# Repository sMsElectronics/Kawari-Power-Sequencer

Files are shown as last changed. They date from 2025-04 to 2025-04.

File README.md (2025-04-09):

# PC Boards available here: 
## [sMs Retro Electronics KoFi Shop](https://ko-fi.com/smsretroelectronics)
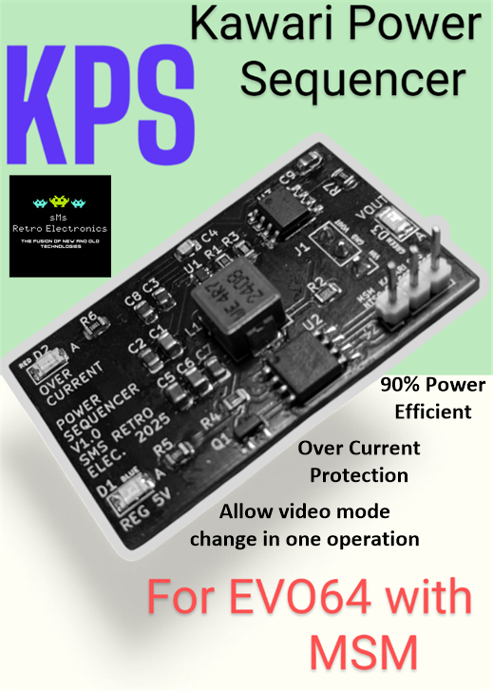
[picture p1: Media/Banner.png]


The Kawari Power Sequencer, known from here on as the “KPS”, is an electronically switched 5V regulator module that has been designed specifically for the EVO64 motherboard to work along side a Kawari VIC II and MSM. The KPS is a reliable, efficient, low noise, high frequency 5V switching regulator which remains very cool unlike linear regulators IC’s such as the common 7805. 

The KPS is installed onto the EVO64 motherboard’s 5V “CAN” regulator location that supplies power only to the VIC II 5V VCC socket pin.

The KPS allows the user to switch video standards on your EVO64 Commodore 64 between NTSC and PAL via the “Multi-Switch Module” MSM and a Kawari VIC II LARGE or SMALL board using a simple keyboard command. It will switch the video standard and recycle the Kawari’s power in one operation. No longer will the user have to manually switch the computers power OFF and ON after setting the video standard with an MSM. 

The KPS incorporates an over current sensing circuit that will sense when the output current goes above 780 mA and turns the 5V output off. A RED LED will indicate this condition. The KPS will remain latched in over current state until the input voltage is turned off and the over current condition is removed.  

sMs Retro Electronics A Division of sMs Electronics 2025
# LED Indicators: 

|LED|COLOR|DESCRIPTION
|:--:|:--|:--|
|D1|BLUE|REGULATOR 5V
|D2|RED|OVER CURRENT 
|D3|GREEN|KAWARI 5V 

 # KPS wiring details

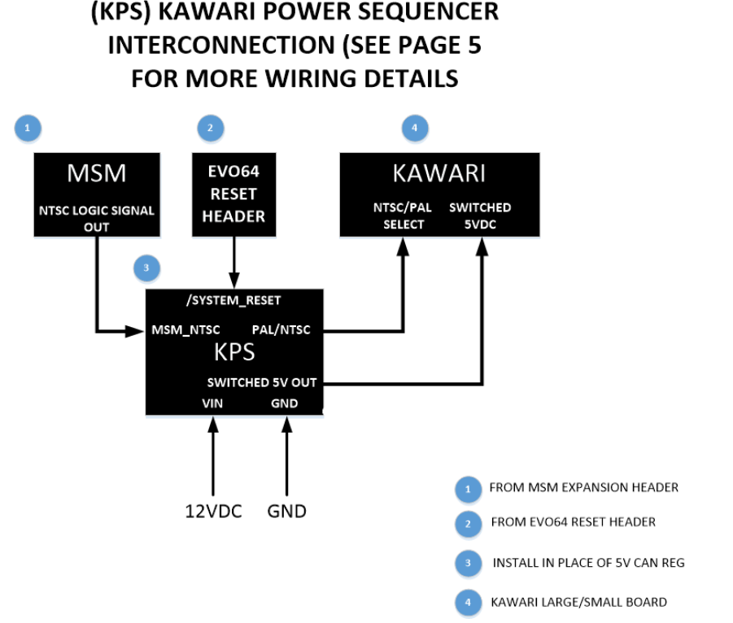
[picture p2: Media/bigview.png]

# Detailed Wiring:

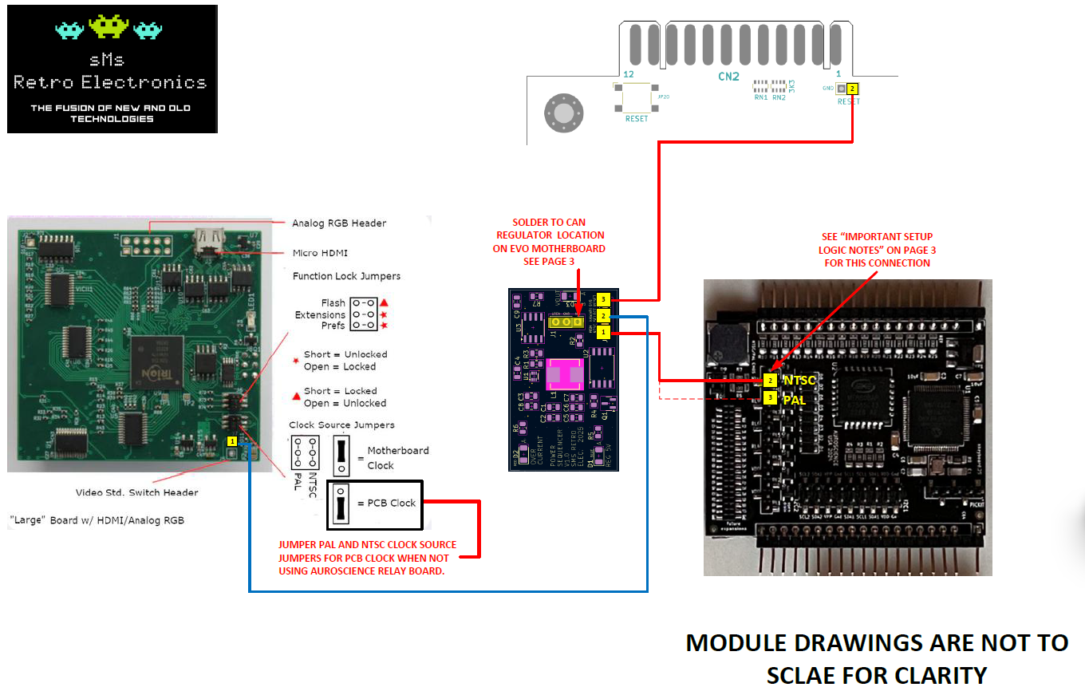
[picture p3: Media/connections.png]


 # KPS Firmware operation

The purpose of the KPS firmware is to allow the Kawari VICII hardware emulator to switch between NTSC and PAL video modes when commanded by an Retrospective EVO64 MSM controller without the need to recycle the computer power. It also provides an OVER CURRENT feature that will switch the power OFF to the Kawari if the current is >= 780 milliamperes. 

The firmware is essentially a state machine that monitors for any change, either a rising or falling edge, from the NTSC (or the PAL) logic output of the MSM and electronically cycles the power OFF then ON to the Kawari Vcc pin. This cycle is as follows: Turn power OFF when a change is detected, keep the power off until the boards RESET is asserted, at this point the power is returned to ON. The NTSC (or the PAL) logic output from the MSM is also routed to the Kawari video select pin header via an open drain MOSFET for 5V to 3.3V translation. 

Over current is latching. If an over current condition is detected, the firmware will turn the power OFF to the Kawari Vcc pin and remain OFF until the next system power cycle. all status is indicated with different color LED's 

 # KPS Build Notes & Cautions 

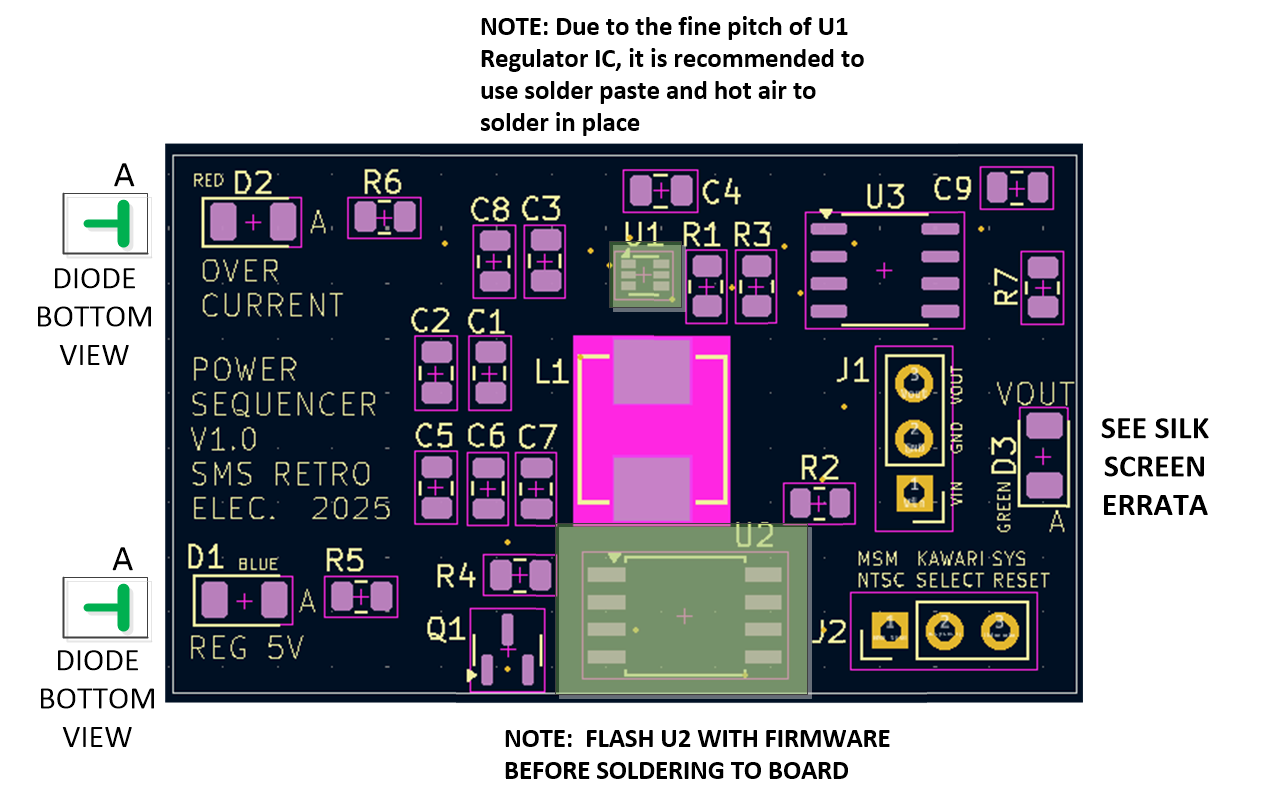
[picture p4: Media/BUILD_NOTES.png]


 If you are building your own KPS, make sure you flash U2 MCU with the firmware provided. All the instructions are provided in the "Flashing and HEX File" folder. When building your KPS, *it is recommended that you populate all components except your programmed U2 ATtiny85V-10S MCU and U3 AP2152A electronic power switch.* This is to prevent damage to these chips in cases where the regulator is not working properly due to errors in construction. These errors can lead to over voltage conditions that will easily damage your chips. It is recommended on first power up to check if the BLUE LED is ON and to measure the core regulator output voltage and check if its 5V +/- 5%. If it is not, then investigate why.    
  
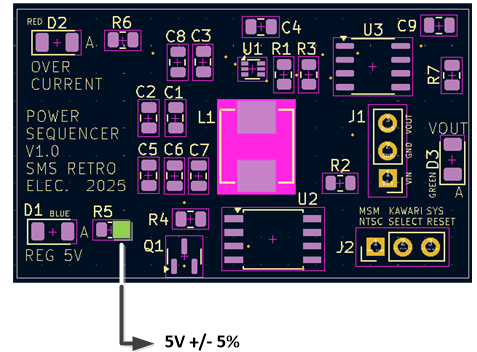
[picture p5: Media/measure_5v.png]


# PCB V1.0 Silkscreen Errata 

Silkscreen anode indication for D3 is incorrect. If D3 is installed as per the silkscreen, the diode will not illuminate. 

# Change FROM:
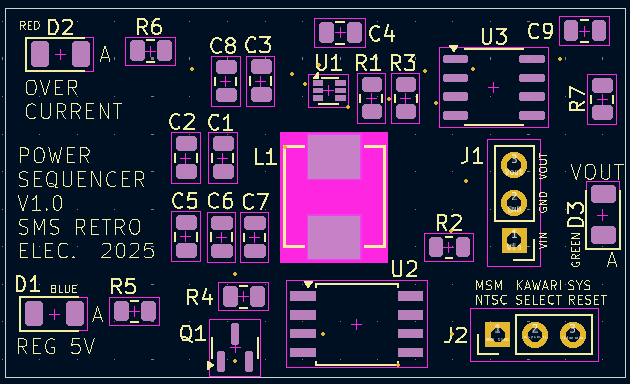
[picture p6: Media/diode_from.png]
  
# Change TO:
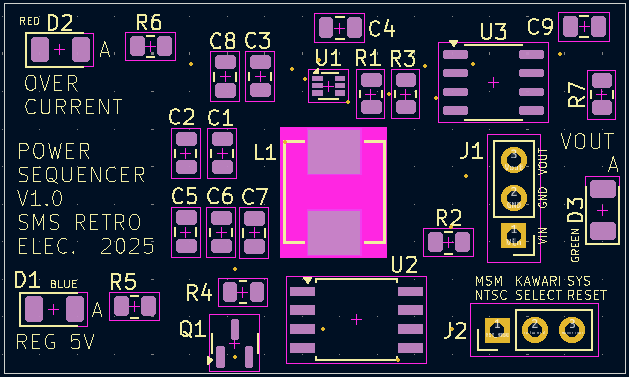
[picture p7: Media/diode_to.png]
  

Be sure to check out the full documentation ! PCB's will be available soon on my KoFi shop.

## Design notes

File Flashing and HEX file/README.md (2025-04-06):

# Flashing code into your ATtiny85

### If you are building a PC board from scratch, the following procedure outlines instructions on how to flash a new, blank, ATtiny85 device using the Xgegcu T48 Programmer. These programmers are widely available on Amazon for very reasonable prices. Below are links to the T48 programmer description and to download the Xgpro application software that will run on your PC. You will also need to download the "firmware_v1.x.hex" file from the "Flashing and HEX file" folder on this git repository and store it in a known location on your PC. This is the file you will LOAD later on in this procedure.  

### Here is a link to a YouTube video that shows the process on how to use the Xgegcu software 

## [Beginners Guide to the Xgecu T48 Programmer](https://youtu.be/36xP4uufo84?si=Jp_okfQR0br4AvkE)

## [Xgegcu T48 Description](http://forums.xgecu.com/viewthread.php?tid=694&extra=page%3D1)

## T48 and typical accessories that come with the bundle on Amazon that cost $79.00 USD as of this writing on 01/27/2025

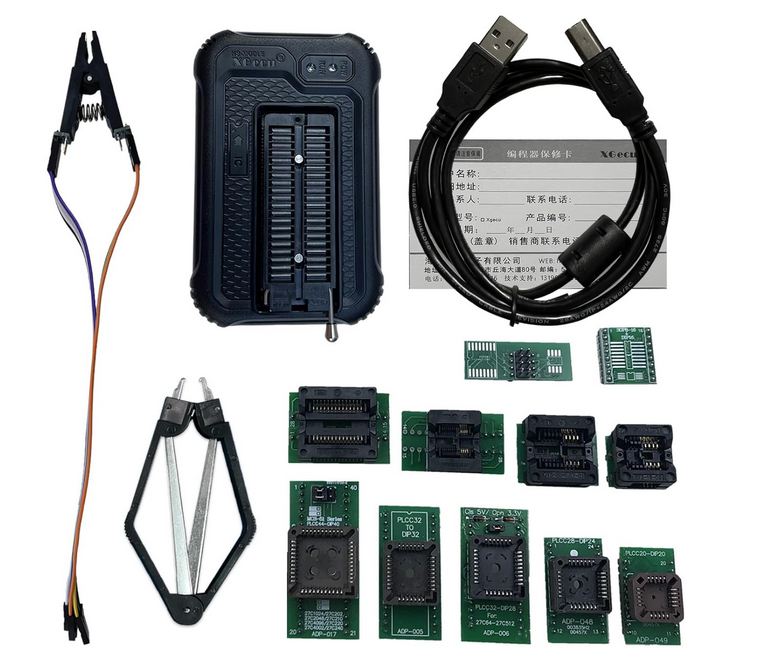
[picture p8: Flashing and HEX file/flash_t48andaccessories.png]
## 

## [Xgegcu Xgpro Application](http://www.xgecu.com/en/download.html?refreshed=1737924728727)

### Install the software per the instructions and run the application once completed. Attach the USB cable to the programmer and connect the other end to your PC's USB port. The PC should recognize the device. 

### After the application opens, the first step is to select your device as shown. Be sure to select the SOIC version. Either selection will work. The "V" only indicates a wider voltage range device. 
 
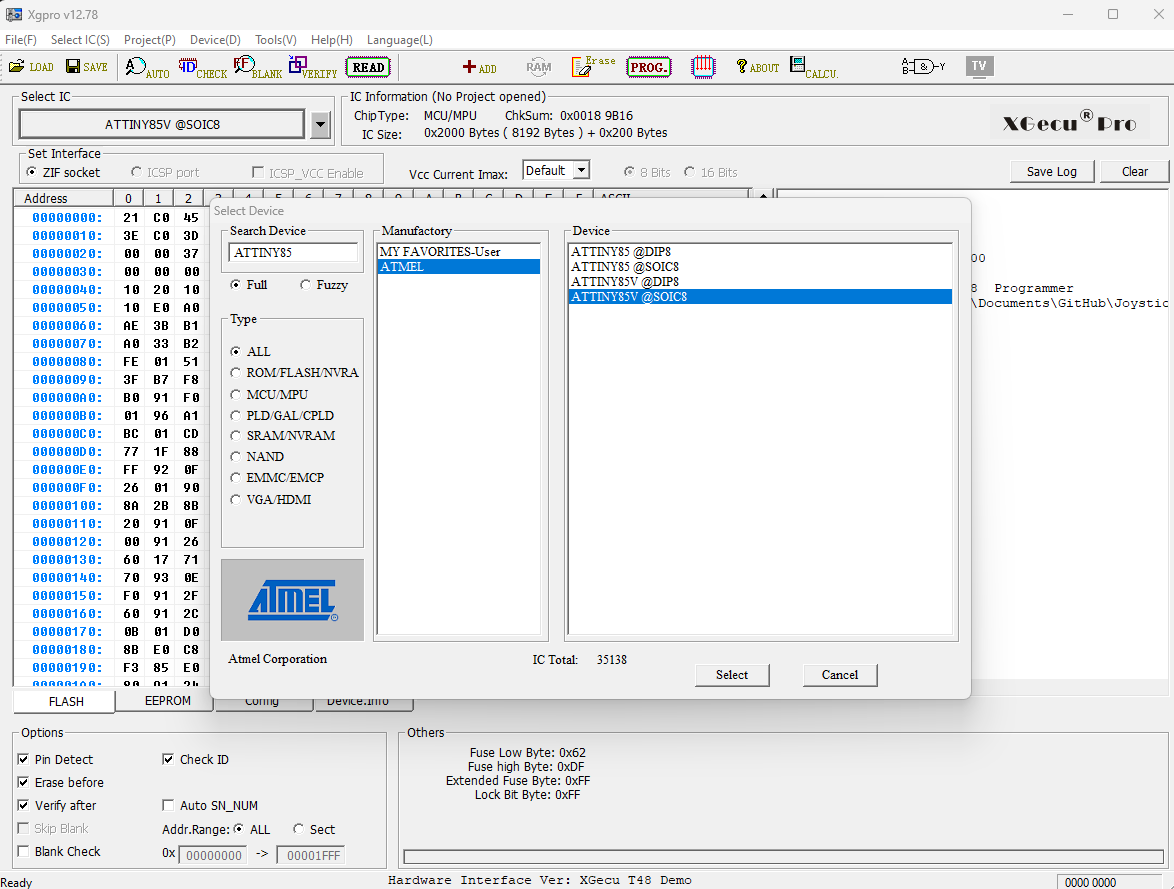
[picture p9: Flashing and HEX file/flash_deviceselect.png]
Select Device


### Locate the adapter (Yours may look different) and place it into the ZIF socket of the programmer. Be sure to orient pin 1 correctly as shown below. Now insert the MCU chip into the adapter as shown being sure that pin 1 is in the correct orientation.   

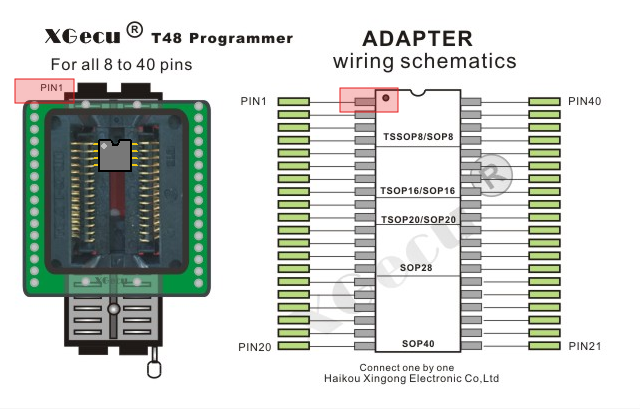
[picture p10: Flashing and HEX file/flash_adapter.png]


### LOAD the HEX file into memory as shown below. Select OK. The memory view should like shown below. 

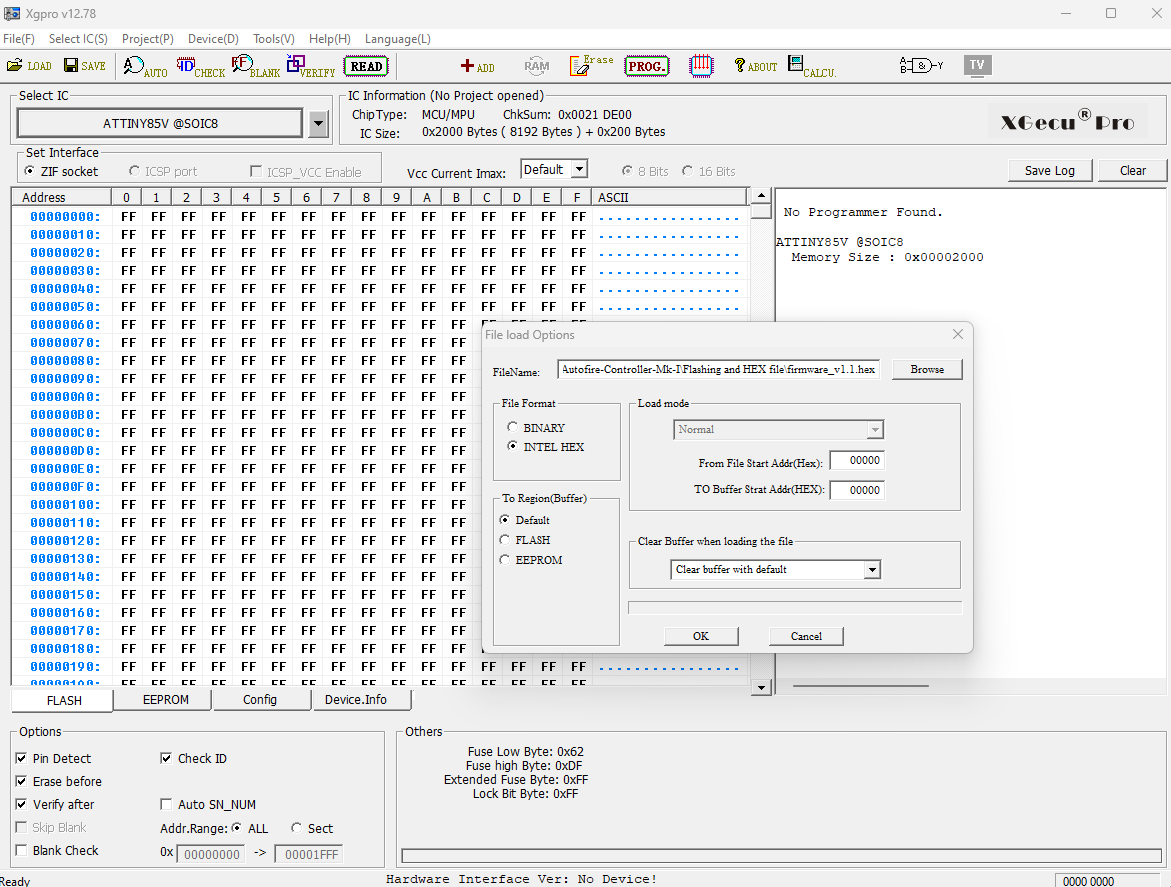
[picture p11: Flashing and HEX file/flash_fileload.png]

### View of memory after LOAD
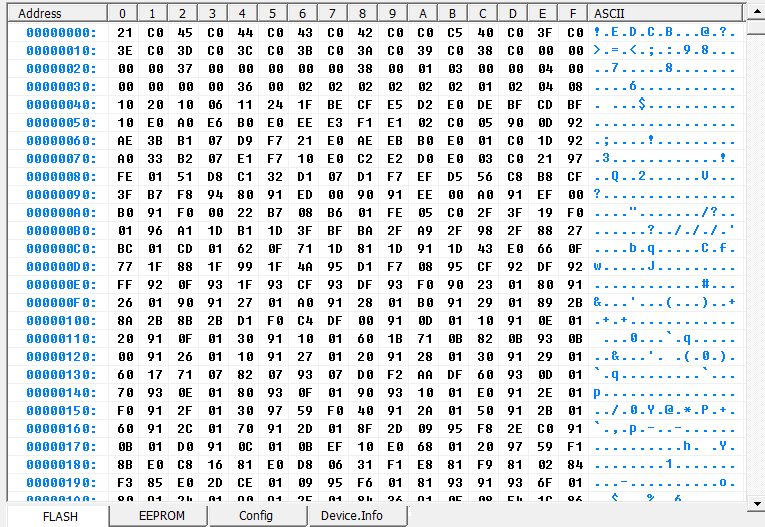
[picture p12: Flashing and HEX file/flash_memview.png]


### Select the fuse options as shown below. This will disable the RESET pin and turn the clock divider OFF thus the MCU will be running the internal oscillator at approximately 4 MHz without the need for an external crystal.    

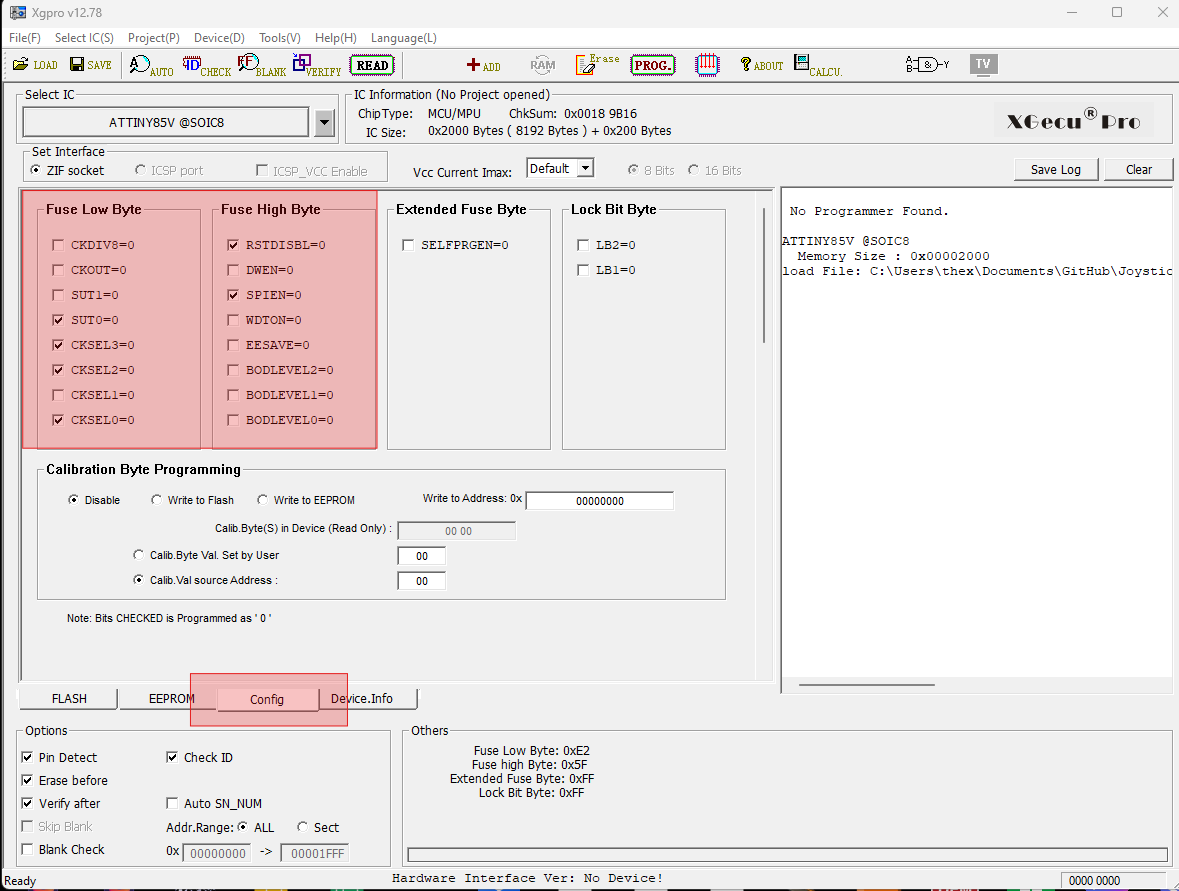
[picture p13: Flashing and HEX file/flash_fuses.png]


### Select PROGRAM and the windows will appear below. Make the selections in the program range. It is only important to select the FLASH and CONFIG memories. The flash memory and fuse bits will only be programmed. 

Now select PROGRAM and the progress will be shown in the window. When completed, SUCCESS should be visible. You can now remove the chip and solder to you PCB.  

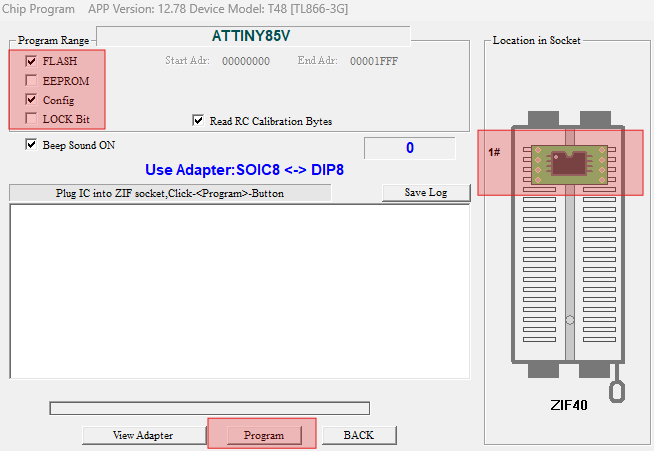
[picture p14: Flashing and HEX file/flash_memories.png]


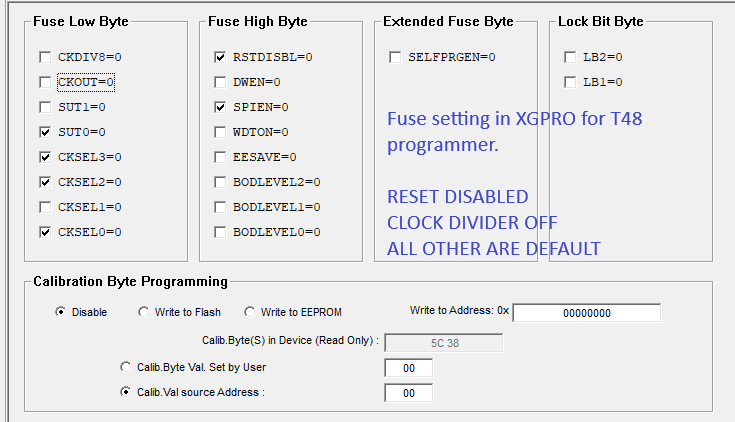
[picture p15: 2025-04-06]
Flashing and HEX file/fuse_settings_t48.PNG

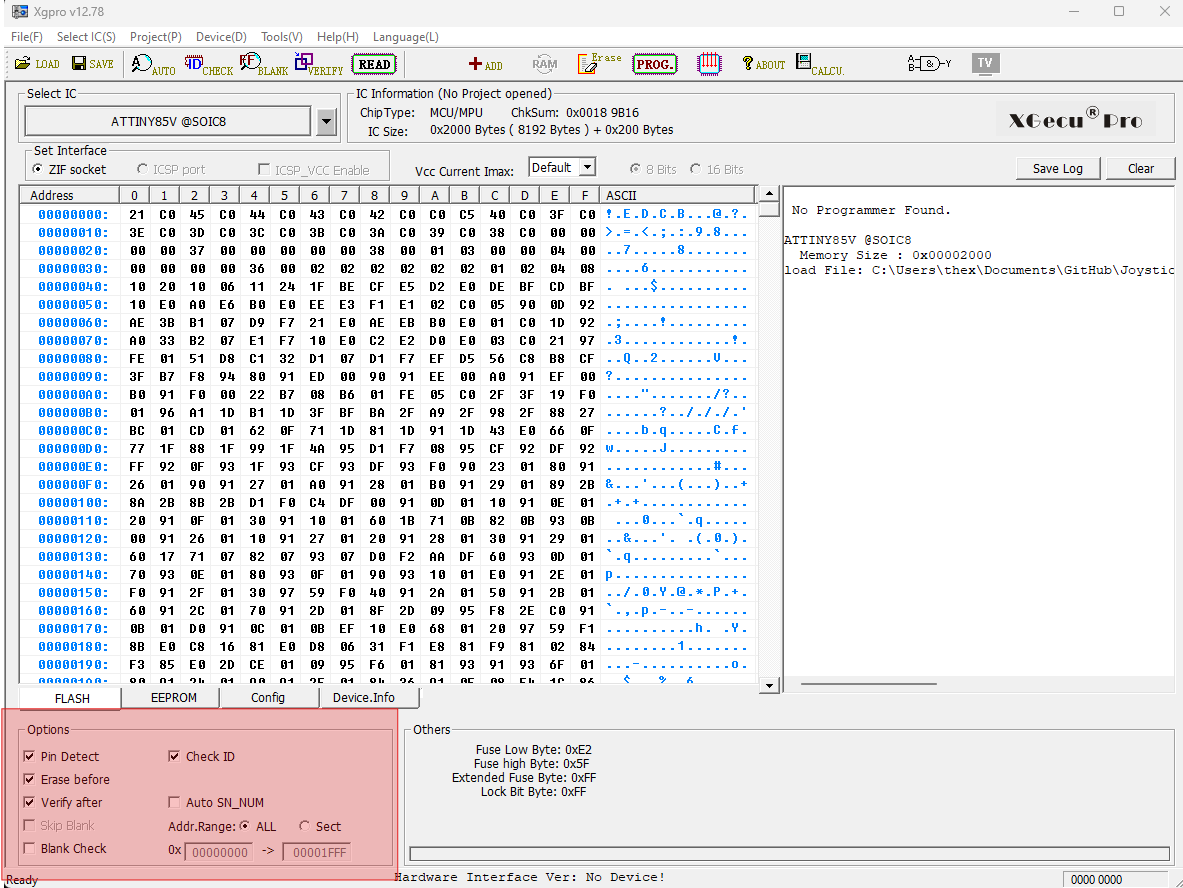
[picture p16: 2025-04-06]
Flashing and HEX file/flash_options.png

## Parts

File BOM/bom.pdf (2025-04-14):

bom

Designation | Footprint
C1 | 0805
C2, C3, C7, C8, 0805
C4 | 0805
C5, C6 | 0805
D1 | 1206
D2 | 1206
D3 | 1206
J1, J2 | PinHeader_1x03_P2.54mm_Vertical
L1 | SMD/SMT
Q1 | SOT-23
R1, R4 | 0805
R2 | 0805
R3 | 0805
R5, R6, R7 | 0805
U1 | SOT-563
U2 | SOIC-8W_5.3x5.3mm_P1.27mm
U3 | SO-8_3.9x4.9mm_P1.27mm

bom

Part Number | Quantity | Value
GRM21BR61E106MA73L | 1 | 10 uF
GCJ21BR71H104MA01L | 5 | .1 uF
C0805C180J3GACTU | 1 | 18 pF
GRM21BR61A226ME44L | 2 | 22 uF
SM1206NBWC-IL | 1 | BLUE LED SMD 1206
SM1206RC-IL | 1 | RED LED SMD 1206
SM1206GC | 1 | GREEN LED SMD 1206
HTSW-110-07-F-S | 2 | Conn_01x03_Pin
74437349047 | 1 | 4.7 uH
| 1 | MOSFET P-CHANNEL
RT0805FRE07100KL | 2 | 100K 1% 1/8W
RT0805FRE07220KL | 1 | 220K 1% 1/8W
RT0805FRE0730KL | 1 | 30K 1% 1/8W
RT0805FRE071KL | 3 | 1K 1% 1/8W
TPS563206DRLR | 1 | Switching Voltage Regulator
ATtiny85V-10S | 1 | ATtiny85V-10S
| 1 | Dual Power Switch

DMP68D1LQ-7

AP2152ASG-13

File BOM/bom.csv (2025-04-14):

Designation | Footprint | Part Number | Quantity | Value
C1 | 0805 | GRM21BR61E106MA73L | 1 | 10 uF
C2, C3, C7, C8, C9 | 0805 | GCJ21BR71H104MA01L | 5 | .1 uF
C4 | 0805 | C0805C180J3GACTU | 1 | 18 pF
C5, C6 | 0805 | GRM21BR61A226ME44L | 2 | 22 uF
D1 | 1206 | SM1206NBWC-IL | 1 | BLUE LED SMD 1206
D2 | 1206 | SM1206RC-IL | 1 | RED LED SMD 1206
D3 | 1206 | SM1206GC | 1 | GREEN LED SMD 1206
J1, J2 | PinHeader_1x03_P2.54mm_Vertical | HTSW-110-07-F-S | 2 | Conn_01x03_Pin
L1 | SMD/SMT | 74437349047 | 1 | 4.7 uH
Q1 | SOT-23 | DMP68D1LQ-7 | 1 | MOSFET P-CHANNEL
R1, R4 | 0805 | RT0805FRE07100KL | 2 | 100K 1% 1/8W
R2 | 0805 | RT0805FRE07220KL | 1 | 220K 1% 1/8W
R3 | 0805 | RT0805FRE0730KL | 1 | 30K 1% 1/8W
R5, R6, R7 | 0805 | RT0805FRE071KL | 3 | 1K 1% 1/8W
U1 | SOT-563 | TPS563206DRLR | 1 | Switching Voltage Regulator
U2 | SOIC-8W_5.3x5.3mm_P1.27mm | ATtiny85V-10S | 1 | ATtiny85V-10S
U3 | SO-8_3.9x4.9mm_P1.27mm | AP2152ASG-13 | 1 | Dual Power Switch

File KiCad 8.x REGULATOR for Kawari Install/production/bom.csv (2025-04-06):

Designator | Footprint | Quantity | Value | LCSC Part #
C1 | 0805 | 1 | 10 uF
C2, C3, C7, C8, C9 | 0805 | 5 | .1 uF
C4 | 0805 | 1 | 18 pF
C5, C6 | 0805 | 2 | 22 uF
D1 | 1206 | 1 | BLUE LED SMD 1206
D2 | 1206 | 1 | RED LED SMD 1206
D3 | 1206 | 1 | GREEN LED SMD 1206
J1, J2 | PinHeader_1x03_P2.54mm_Vertical | 2 | Conn_01x03_Pin
L1 | WE-LHMI_7050 | 1 | 4.7 uH
Q1 | SOT-23 | 1 | 2N7002
R1, R4 | 0805 | 2 | 100K
R2 | 0805 | 1 | 220K
R3 | 0805 | 1 | 30K
R5, R6, R7 | 0805 | 3 | 1K
U1 | SOT-563 | 1 | TPS563206DRLR
U2 | SOIC-8W_5.3x5.3mm_P1.27mm | 1 | ATtiny85V-10S
U3 | SO-8_3.9x4.9mm_P1.27mm | 1 | AP2152A

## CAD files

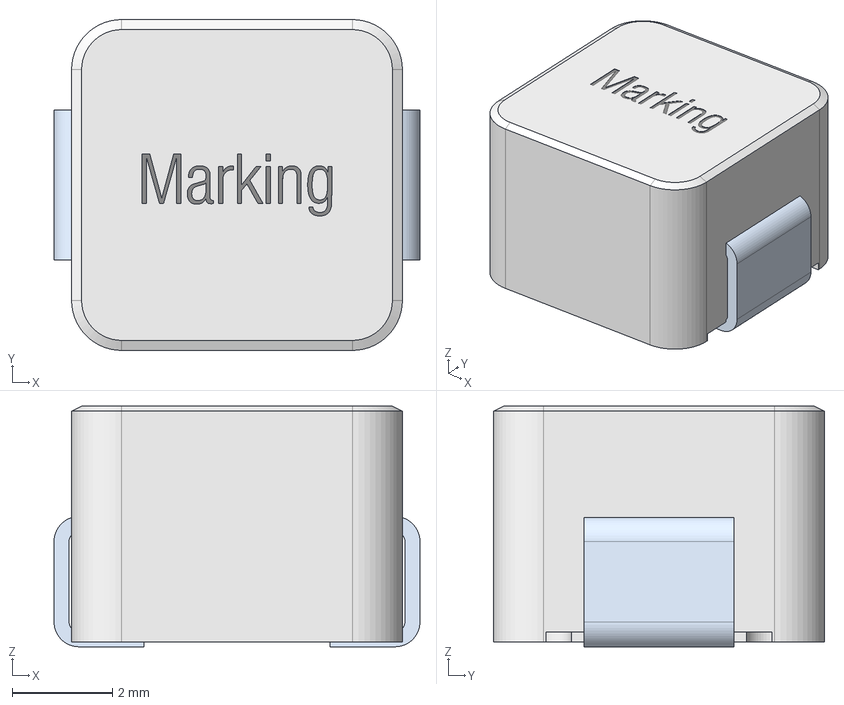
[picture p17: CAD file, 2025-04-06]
KiCad 8.x REGULATOR for Kawari Install/NEW Design/74437349047/WE-LHMI_7050.step
7.30 x 6.60 x 4.80 mm

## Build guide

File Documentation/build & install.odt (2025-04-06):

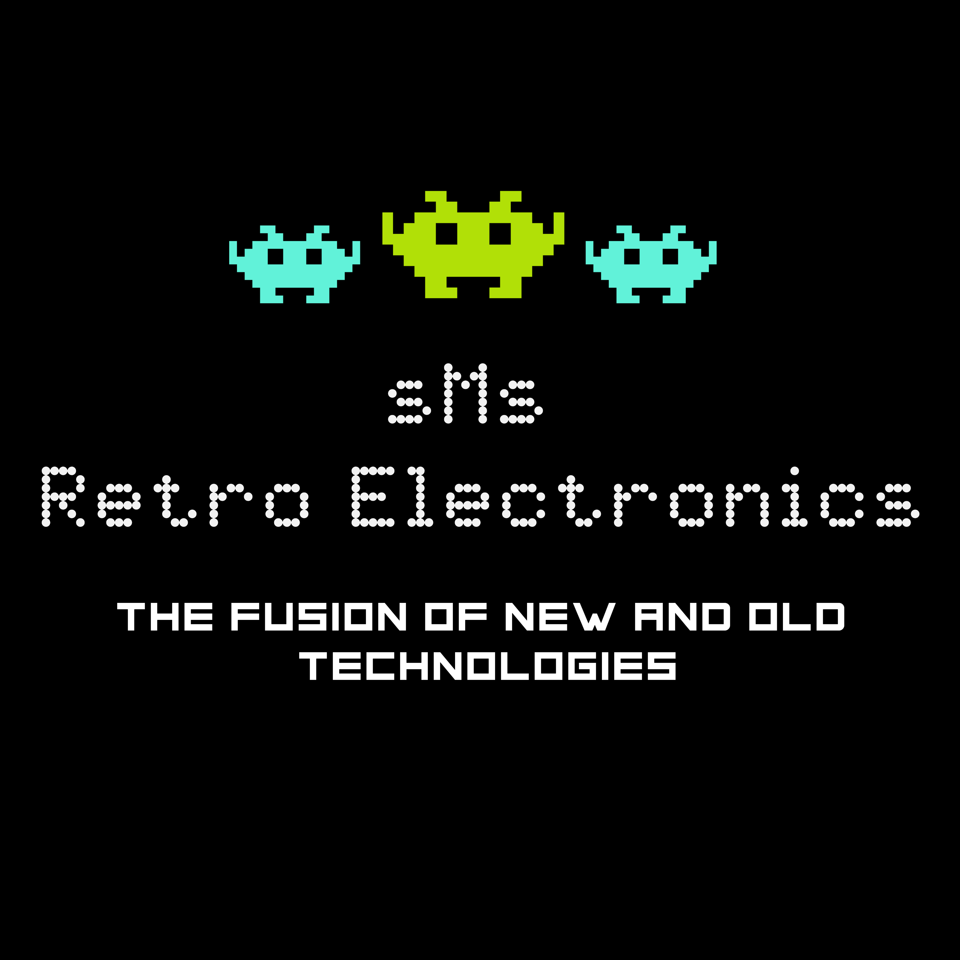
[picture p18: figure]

EVO64 KPS (Kawari Power Sequencer)

PC Board Version V1.0 : MCU Firmware Version V1.0

The document covers:

INSTALLATION & OPERATION

for Support: Bill Manganaro thex@optonline.net

or give a shout on the Discord channel: C64EVO, Expansions / Add-Ons

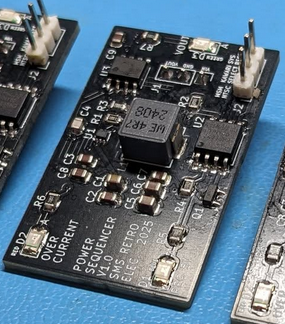
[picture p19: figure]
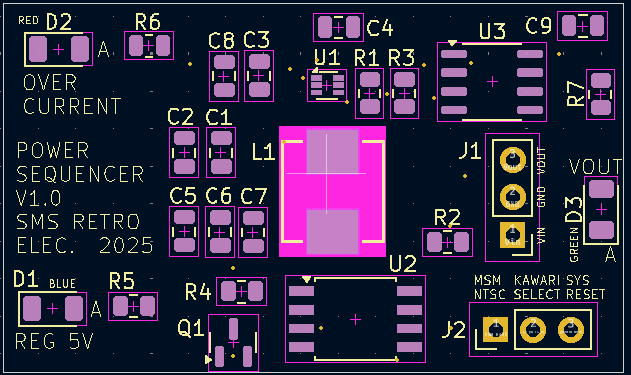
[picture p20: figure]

Whats is the Kawari Power Sequencer?

The Kawari Power Sequencer, known from here on as the “KPS”, is an electronically switched 5V regulator module that has been designed specifically for the EVO64 motherboard to work along side a Kawari VIC II and MSM. The KPS is a reliable, efficient, low noise, high frequency 5V switching regulator which remains very cool unlike linear regulators IC’s such as the common 7805.

The KPS is installed onto the EVO64 motherboard’s 5V “CAN” regulator location that supplies power only to the VIC II 5V VCC socket pin.

The KPS allows the user to switch video standards on your EVO64 Commodore 64 between NTSC and PAL via the “Multi-Switch Module” MSM and a Kawari VIC II LARGE or SMALL board using a simple keyboard command. It will switch the video standard and recycle the Kawari’s power in one operation. No longer will the user have to manually switch the computers power OFF and ON after setting the video standard with an MSM.

Over Current Safety Feature

The KPS incorporates an over current sensing circuit that will sense when the output current goes above 780 mA and turns the 5V output off. A RED LED will indicate this condition. The KPS will remain latched in over current state until the input voltage is turned off and the over current condition is removed.

This document illustrates all the details necessary to install the KPS, wire the necessary connections, and operate your KPS. The board you receive has been fully tested before shipping to insure that it works as designed.

Connector and Indicator Reference

1) Vout INDICATOR. - Green LED that indicates 5V power is present to the Kawari VIC II.

2) OVER CURRENT INDICATOR. - Red LED that indicates an over current condition is present.

3) REGULATOR INDICATOR. - Blue LED that indicates the internal 5V is working.

4) KPS INPUT AND OUTPUT CONNECTOR (J2)

PIN 1 [SQUARE PAD] LOGIC SIGNAL FROM MSM (INPUT)

PIN 2 KAWARI SELECT SIGNAL TO KAWARI (OUTPUT)

PIN 3 SYSTEM RESET SIGNAL (INPUT)

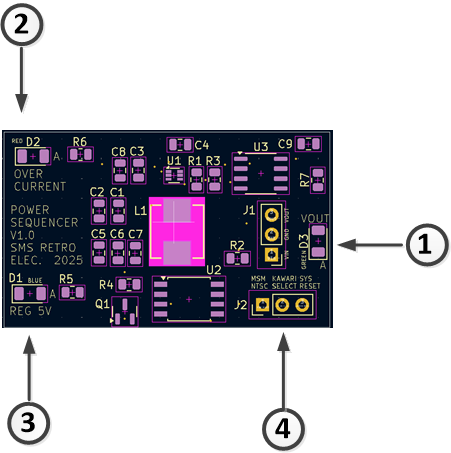
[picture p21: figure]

Overall View of Installation

The following diagram shows all the components necessary for the system to work.

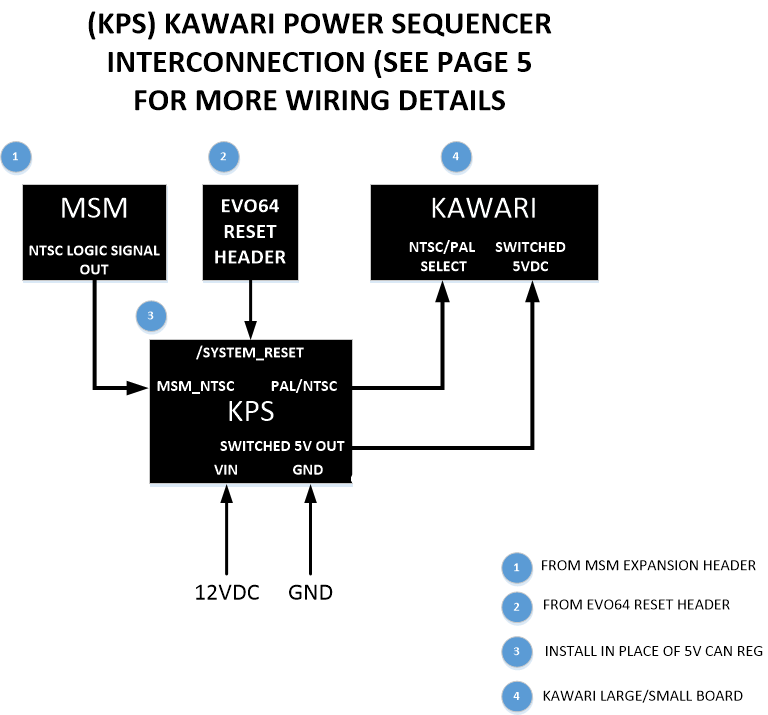
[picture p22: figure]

Detailed Installation

If a 5V regulator is already installed on your EVO motherboard, desolder it and clear the pad holes of any remaining solder. Install the KPS as shown below noting the position of the J1 pin header. Also, please read the “IMPORTANT SETUP LOGIC NOTES” so that you use the correct logic output (NTSC or PAL) from the MSM based on your VIC II emulation mode saved in the Kawari setup utility.

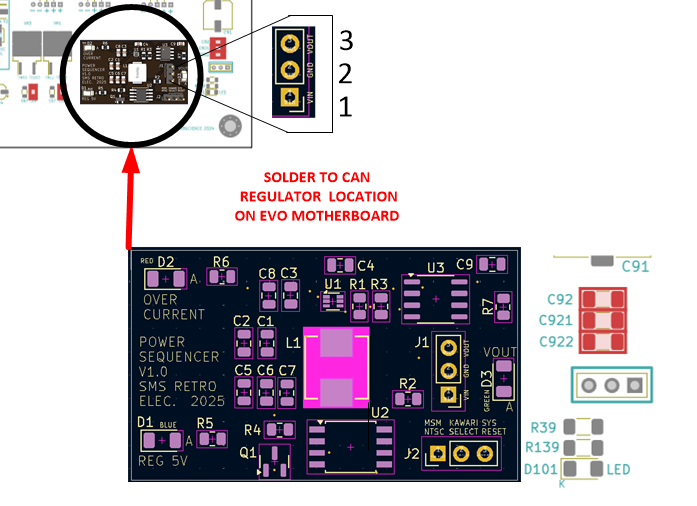
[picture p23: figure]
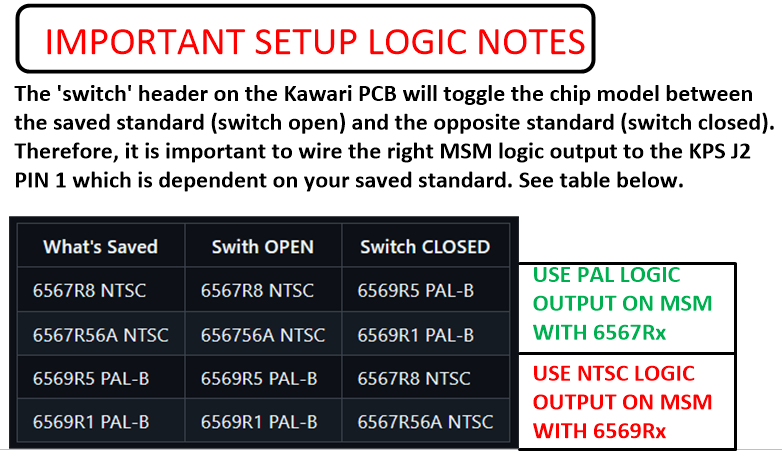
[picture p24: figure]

On your Kawari, if you do not have a VICII oscillator control module, set your clock select jumpers to “PCB Clock” as shown in the diagram below and connect the wiring as shown. Its important to check all the connections after you’re done.

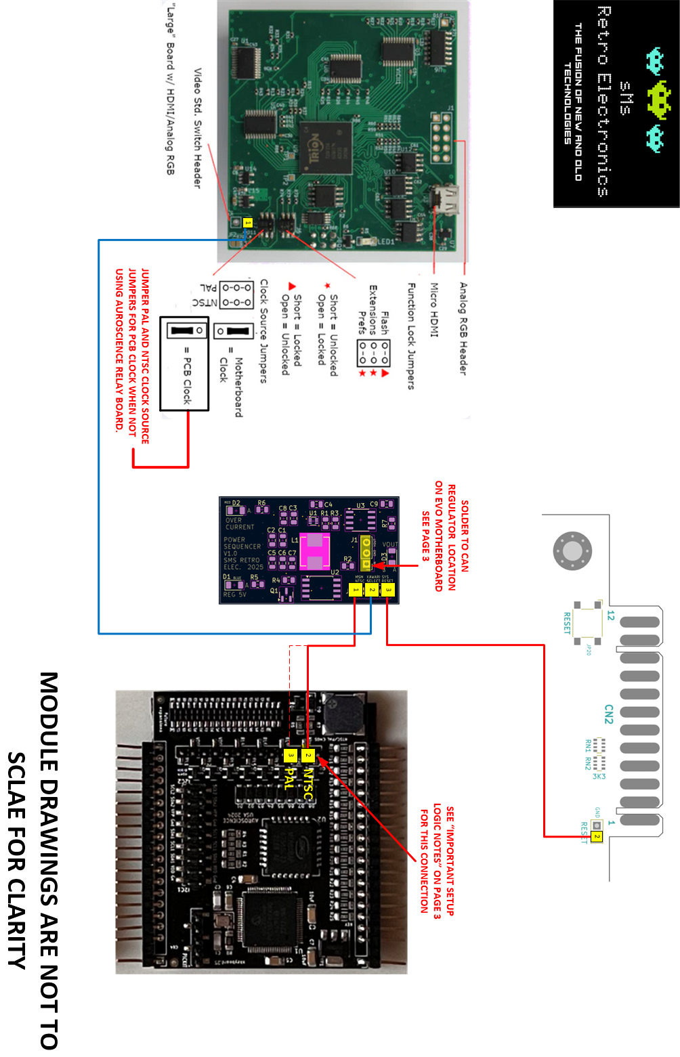
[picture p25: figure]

First Turn On

Setup your computer with an HDMI monitor connected (If using kawari Large) and turn the computer power on. On the KPS, the green LED (1) and blue LED (3) should be on and the red LED (2) should be off. Your kawari red LED should also be on. You should see a display like you normally do on your monitor. If you see this then you are in good shape. If the KPS red LED is on, and the green LED is off, this indicates an over current issue of >780 mA and must be investigated. The MSM LCD should look normal as shown with your current settings. We are interested in the VID: PAL or NTSC portion of the LCD. Your monitor should always reflect the setting shown on the MSM LCD.

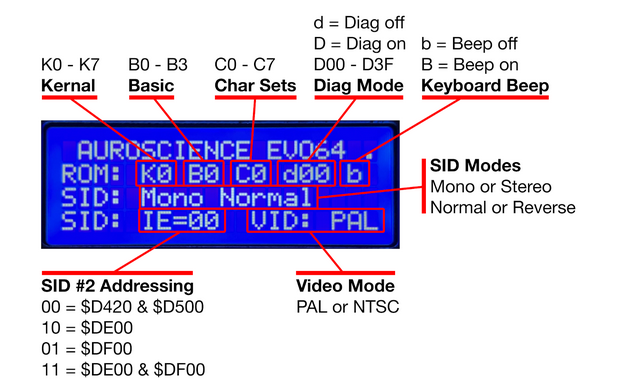
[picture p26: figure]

To change the VIC II video mode, see the instructions below. When changing the video mode, the KPS green and Kawari red LED’s will flash for about a second and then remain on. This indicates the Kawari power has been successfully cycled off then on in order for it to configure itself properly. The video output standard should now be what’s indicated on your MSM’s LCD. Here is a quick sanity check to make sure you are in the correct video standard. Type this BASIC command at the computer prompt and if it returns a “0”, you’re in NTSC. If it returns a “1”, you’re in PAL

PRINT PEEK (678)

Instructions to Change Video Mode on MSM:

VICII VIDEO MODE: video

This command enables you to toggle between PAL and NTSC, as long as you have all the necessary add-ons. To toggle between video modes, you simply enter the COMMAND MODE sequence (Reference below), followed by video and RETURN.

- After changing a video mode, Kawari will be automatically power cycled by the KPS module you’ve just installed.

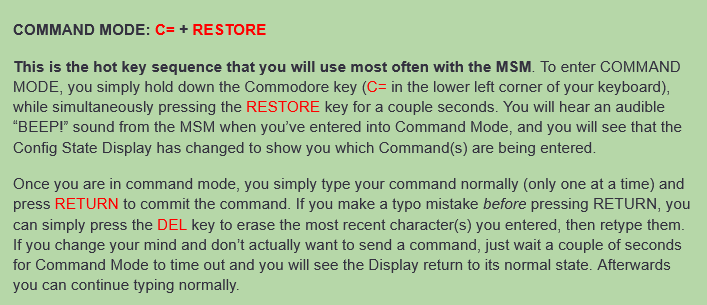
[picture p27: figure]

(https://docs.google.com/document/d/1dWGB7BDyYcx3Wr9RBiRH9s14tvGeOEsOeAum02HLLDU/edit?tab=t.0)The web link to the full MSM documentation is located here:

WEB LINK TO : MSM DOCUMENTATION (https://docs.google.com/document/d/1dWGB7BDyYcx3Wr9RBiRH9s14tvGeOEsOeAum02HLLDU/edit?tab=t.0)

If everything has worked than your installation has been a success. If things do not seem to be working correctly, then proceed to the following troubleshooting table.

TROUBLESHOOTING

SYMPTOM | ACTION
No LED’s on KPS are on | Check for 12V at the Vin of the KPS
Just the Blue LED is on | Check that the KPS is connected to the mainboard’s RESET header and that the connection is on the correct pin of the header
The red LED is on | The is a short at the KPS output. Remove the Kawari and see if the short goes away.
The power cycling does not occur | Check that the KPS is connected to the MSM “NTSC” logic output. Make sure the connection is on the correct pin.

Page 9 sMs Retro Electronics KPS Rev 1.0 Rev “A”

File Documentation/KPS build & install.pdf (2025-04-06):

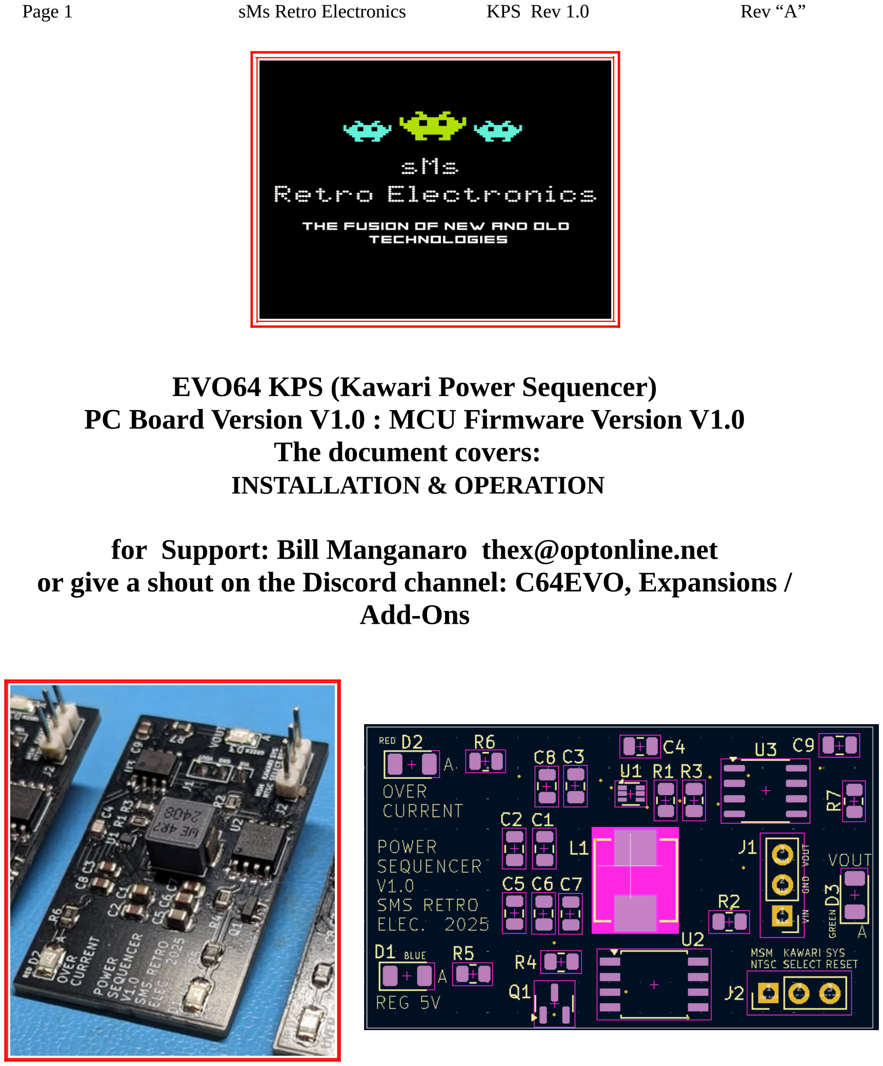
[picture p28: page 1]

Page 1 | sMs Retro Electronics | KPS Rev 1.0 | Rev “A”

EVO64 KPS (Kawari Power Sequencer) PC Board Version V1.0 : MCU Firmware Version V1.0 The document covers:
INSTALLATION & OPERATION

for Support: Bill Manganaro thex@optonline.net or give a shout on the Discord channel: C64EVO, Expansions / Add-Ons

Page 2 | sMs Retro Electronics | KPS Rev 1.0 | Rev “A”
Whats is the Kawari Power Sequencer?

The Kawari Power Sequencer, known from here on as the “KPS”, is an electronically switched 5V regulator module that has been designed specifically for the EVO64 motherboard to work along side a Kawari VIC II and MSM. The KPS is a reliable, efficient, low noise, high frequency 5V switching regulator which remains very cool unlike linear regulators IC’s such as the common 7805.

The KPS is installed onto the EVO64 motherboard’s 5V “CAN” regulator location that supplies power only to the VIC II 5V VCC socket pin.

The KPS allows the user to switch video standards on your EVO64 Commodore 64 between NTSC and PAL via the “Multi-Switch Module” MSM and a Kawari VIC II LARGE or SMALL board using a simple keyboard command. It will switch the video standard and recycle the Kawari’s power in one operation. No longer will the user have to manually switch the computers power OFF and ON after setting the video standard with an MSM.

Over Current Safety Feature

The KPS incorporates an over current sensing circuit that will sense when the output current goes above 780 mA and turns the 5V output off. A RED LED will indicate this condition. The KPS will remain latched in over current state until the input voltage is turned off and the over current condition is removed.

This document illustrates all the details necessary to install the KPS, wire the necessary connections, and operate your KPS. The board you receive has been fully tested before shipping to insure that it works as designed.

Page 3 | sMs Retro Electronics | KPS Rev 1.0 | Rev “A”
Connector and Indicator Reference
1) Vout INDICATOR. - Green LED that indicates 5V power is present to the Kawari VIC II.
2) OVER CURRENT INDICATOR. - Red LED that indicates an over current condition is present.
3) REGULATOR INDICATOR. - Blue LED that indicates the internal 5V is working.
4) KPS INPUT AND OUTPUT CONNECTOR (J2)
PIN 1 [SQUARE PAD] LOGIC SIGNAL FROM MSM | (INPUT)
PIN 2 KAWARI SELECT SIGNAL TO KAWARI | (OUTPUT)
PIN 3 SYSTEM RESET SIGNAL | (INPUT)

Page 4 | sMs Retro Electronics | KPS Rev 1.0 | Rev “A”
Overall View of Installation

The following diagram shows all the components necessary for the system to work.

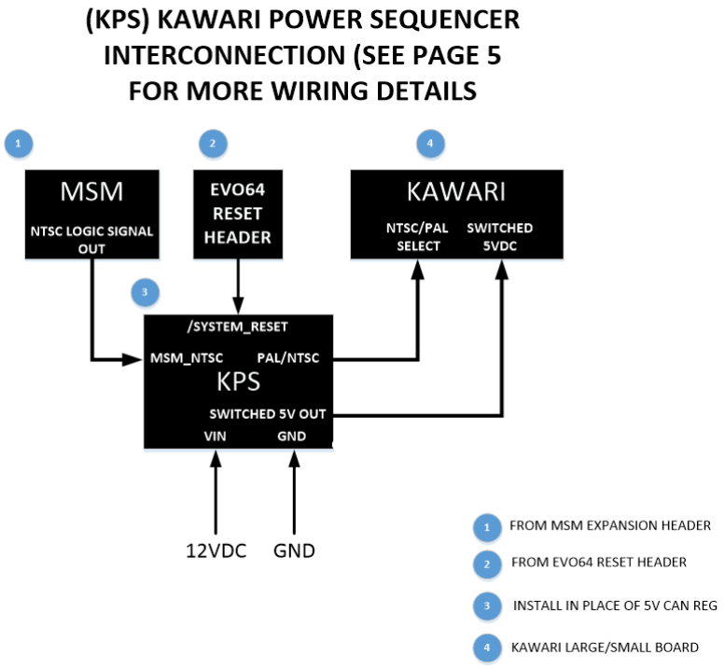
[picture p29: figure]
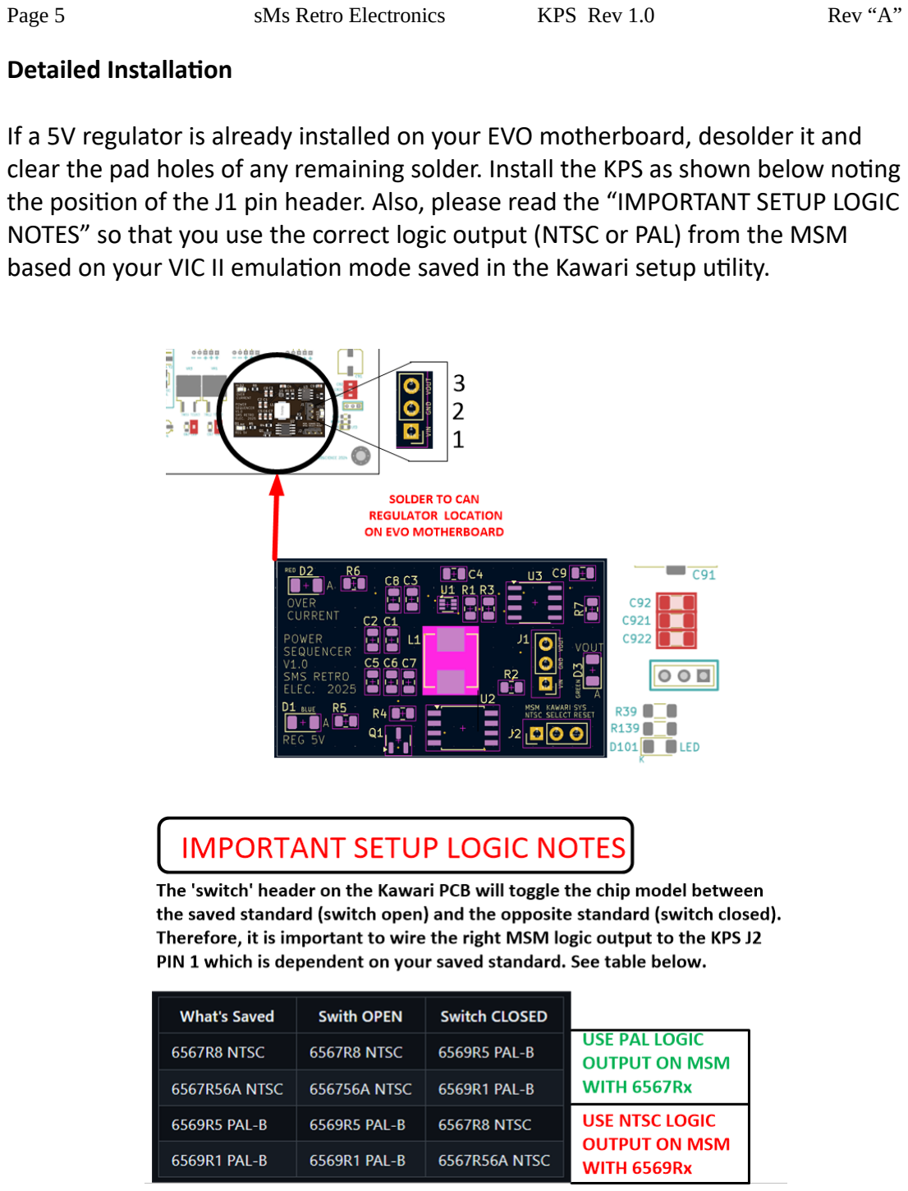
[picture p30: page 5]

Page 5 | sMs Retro Electronics | KPS Rev 1.0 | Rev “A”
Detailed Installation

If a 5V regulator is already installed on your EVO motherboard, desolder it and clear the pad holes of any remaining solder. Install the KPS as shown below noting the position of the J1 pin header. Also, please read the “IMPORTANT SETUP LOGIC NOTES” so that you use the correct logic output (NTSC or PAL) from the MSM based on your VIC II emulation mode saved in the Kawari setup utility.

Page 6 | sMs Retro Electronics | KPS Rev 1.0 | Rev “A”
On your Kawari, if you do not have a VICII oscillator control module, set your clock select jumpers to “PCB Clock” as shown in the diagram below and connect the wiring as shown. Its important to check all the connections after you’re done.

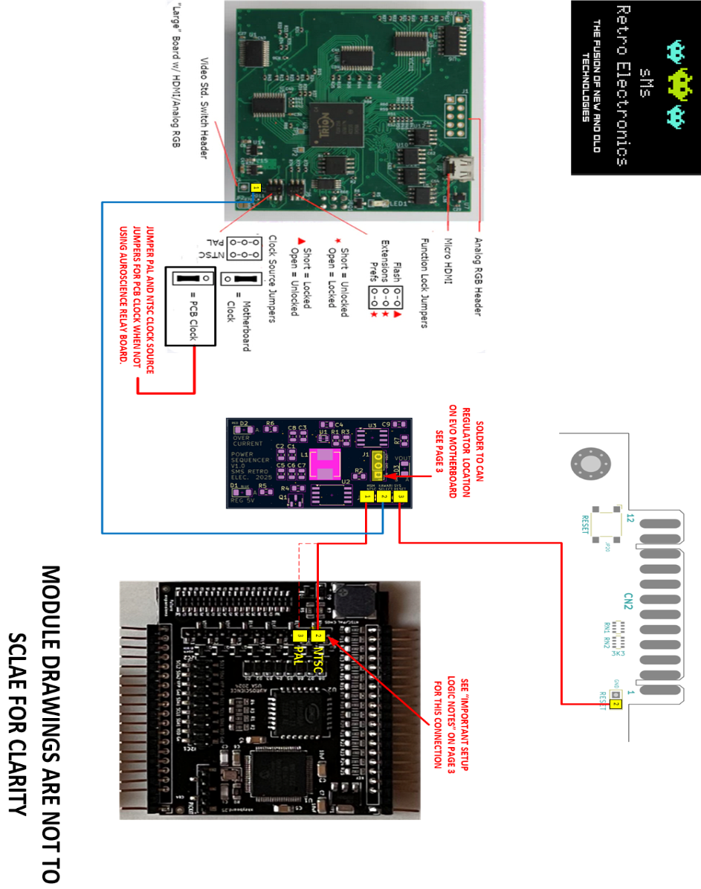
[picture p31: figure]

Page 7 | sMs Retro Electronics | KPS Rev 1.0 | Rev “A”

First Turn On


Setup your computer with an HDMI monitor connected (If using kawari Large) and turn the computer power on. On the KPS, the green LED (1) and blue LED (3) should be on and the red LED (2) should be off. Your kawari red LED should also be on. You should see a display like you normally do on your monitor. If you see this then you are in good shape. If the KPS red LED is on, and the green LED is off, this indicates an over current issue of >780 mA and must be investigated. The MSM LCD should look normal as shown with your current settings. We are interested in the VID: PAL or NTSC portion of the LCD. Your monitor should always reflect the setting shown on the MSM LCD.

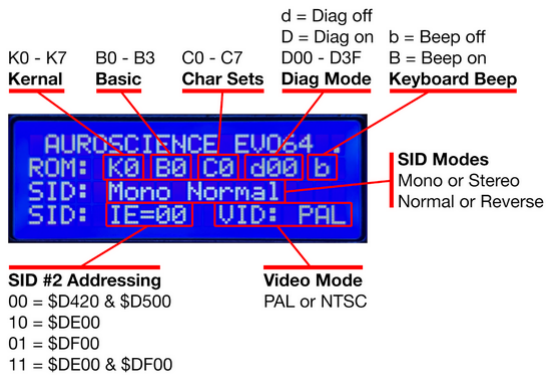
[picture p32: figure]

Page 8 | sMs Retro Electronics | KPS Rev 1.0 | Rev “A”
To change the VIC II video mode, see the instructions below. When changing the video mode, the KPS green and Kawari red LED’s will flash for about a second and then remain on. This indicates the Kawari power has been successfully cycled off then on in order for it to configure itself properly. The video output standard should now be what’s indicated on your MSM’s LCD. Here is a quick sanity check to make sure you are in the correct video standard. Type this BASIC command at the computer prompt and if it returns a “0”, you’re in NTSC. If it returns a “1”, you’re in PAL
PRINT PEEK (678)
Instructions to Change Video Mode on MSM:
VICII VIDEO MODE: video

This command enables you to toggle between PAL and NTSC, as long as you have all the necessary add-ons. To toggle between video modes, you simply enter the COMMAND MODE sequence (Reference below), followed by video and RETURN.

- After changing a video mode, Kawari will be automatically power cycled by the KPS module you’ve just installed.

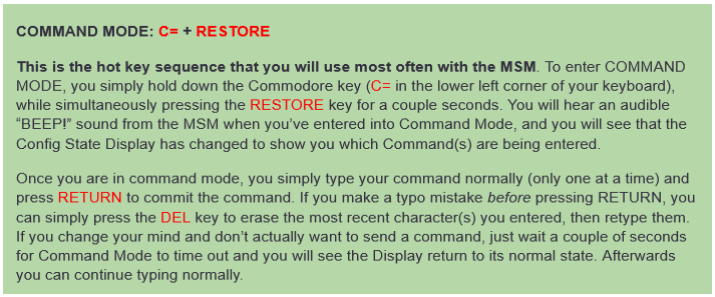
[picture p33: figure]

Page 9 | sMs Retro Electronics | KPS Rev 1.0 | Rev “A”
The web link to the full MSM documentation is located here:

WEB LINK TO : MSM DOCUMENTATION (https://docs.google.com/document/d/1dWGB7BDyYcx3Wr9RBiRH9s14tvGeOEsOeAum02HLLDU/edit?tab=t.0)

If everything has worked than your installation has been a success. If things do not seem to be working correctly, then proceed to the following troubleshooting table.

TROUBLESHOOTING

SYMPTOM | ACTION
No LED’s on KPS are on | Check for 12V at the Vin of the KPS
Just the Blue LED is on | Check that the KPS is connected to the mainboard’s RESET header and that the connection is on the correct pin of the header
The red LED is on | The is a short at the KPS output. Remove the Kawari and see if the short goes away.
The power cycling does not occur | Check that the KPS is connected to the MSM “NTSC” logic output. Make sure the connection is on the correct pin.

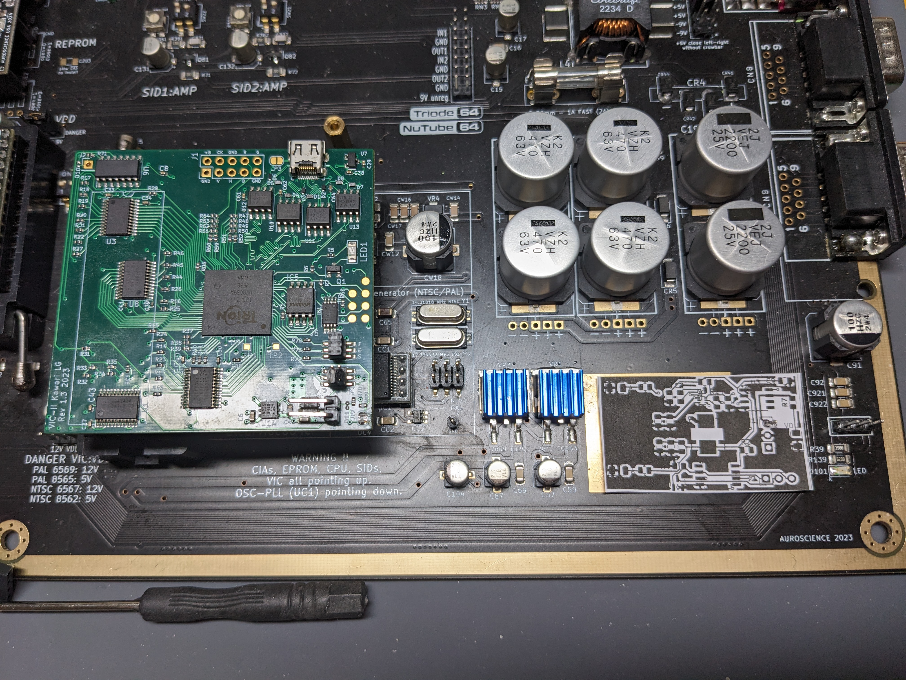
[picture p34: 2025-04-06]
KiCad 8.x REGULATOR for Kawari Install/PXL_20250223_172702716.jpg

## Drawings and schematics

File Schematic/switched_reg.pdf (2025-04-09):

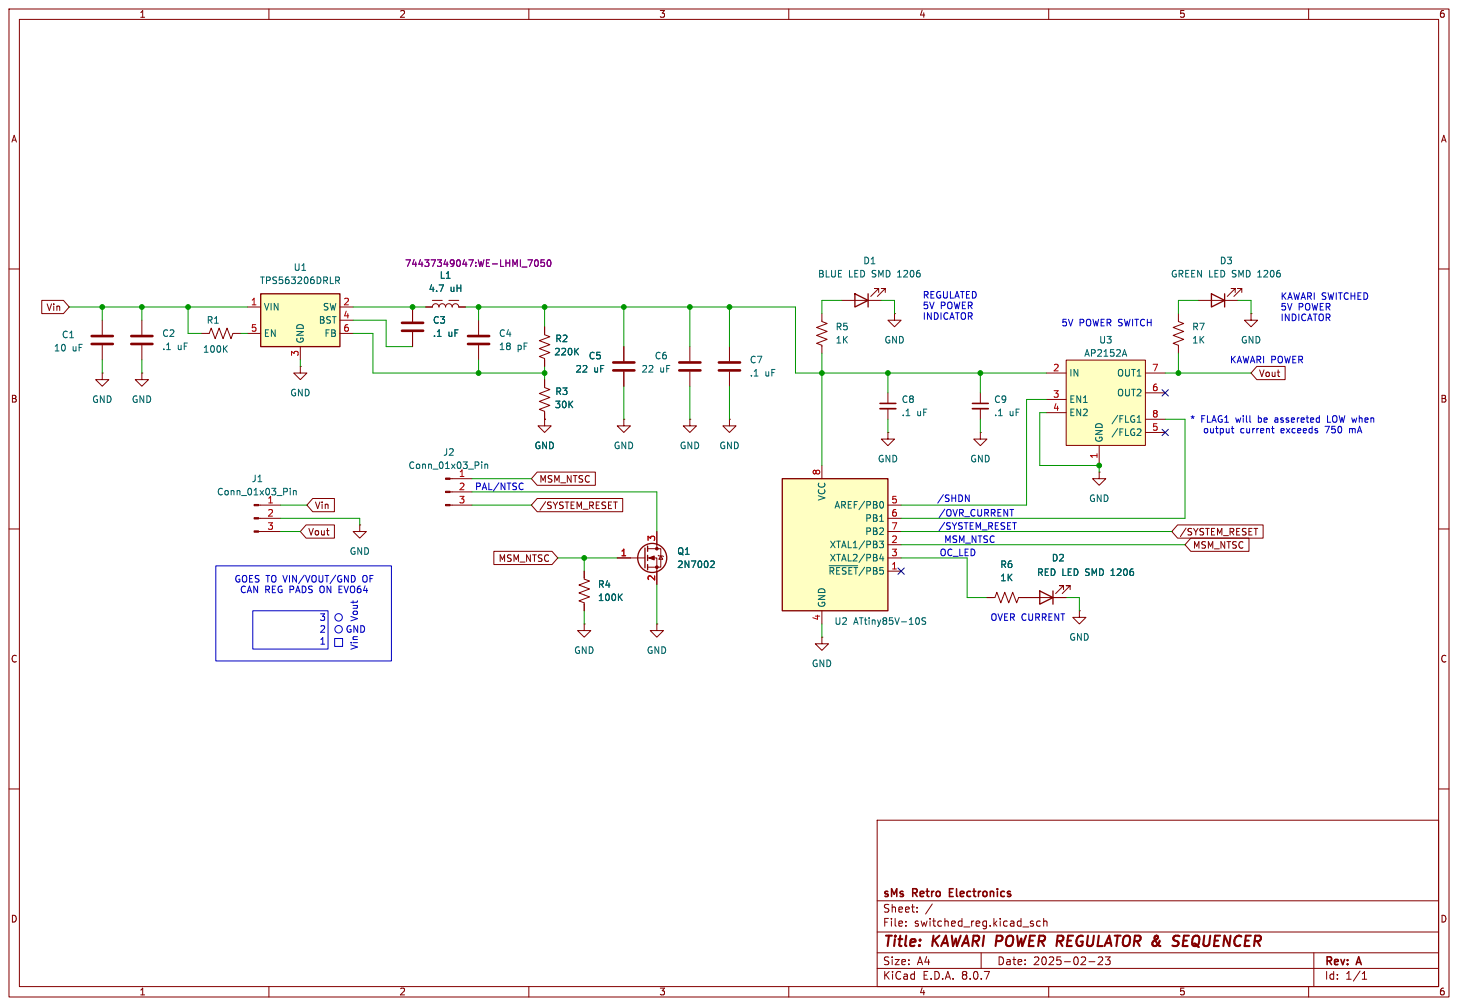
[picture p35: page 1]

Id: 1/1 Title: KAWARI POWER REGULATOR & SEQUENCER

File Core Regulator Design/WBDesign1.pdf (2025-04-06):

## WEBENCH ® Design Report

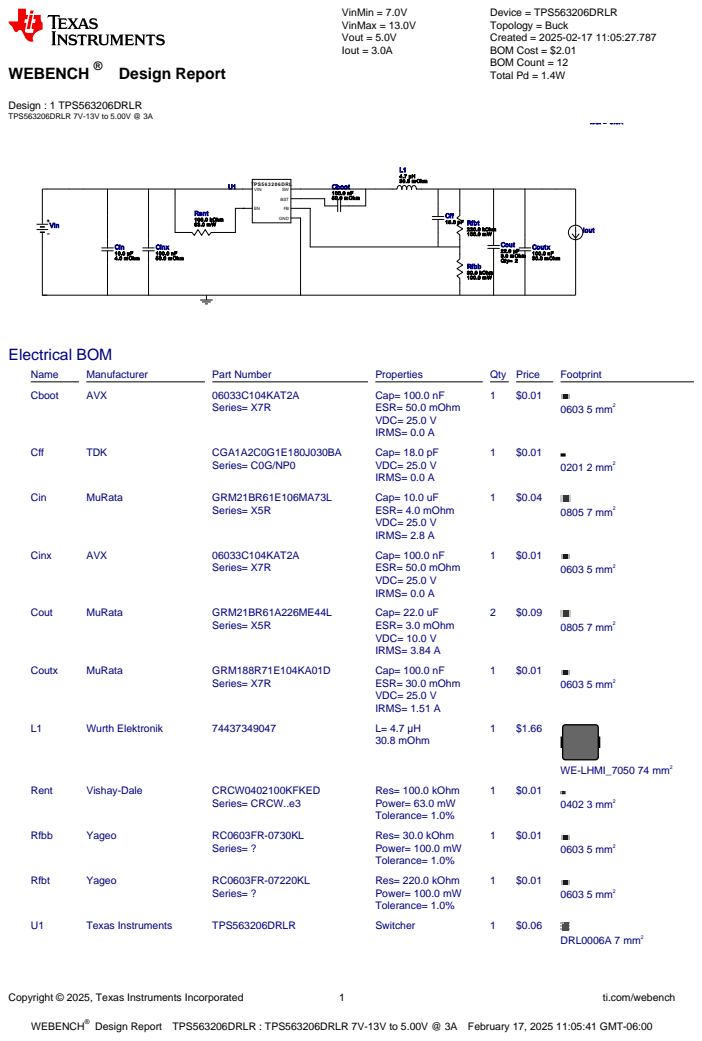
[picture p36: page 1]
Copyright © 2025, Texas Instruments Incorporated; ti.com/webench; WEBENCH®; Design : 1 TPS563206DRLR TPS563206DRLR 7V-13V to 5.00V @ 3A; VinMin = 7.0V VinMax = 13.0V Vout = 5.0V Iout = 3.0A; Device = TPS563206DRLR Topology = Buck Created = 2025-02-17 11:05:27.787 BOM Cost = $2.01 BOM Count = 12 Total Pd = 1.4W; Cboot 100.0 nF 50.0 m Ohm; Cff 18.0 pF Rfbt 220.0 kOhm 100.0 m W; Rfbb 30.0 kOhm 100.0 m W; Rent 100.0 kOhm 63.0 m W; L1 4.7 µH 30.8 m Ohm; Coutx 100.0 nF 30.0 m Ohm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

Design Report TPS563206DRLR : TPS563206DRLR 7V-13V to 5.00V @ 3A February 17, 2025 11:05:41 GMT-06:00

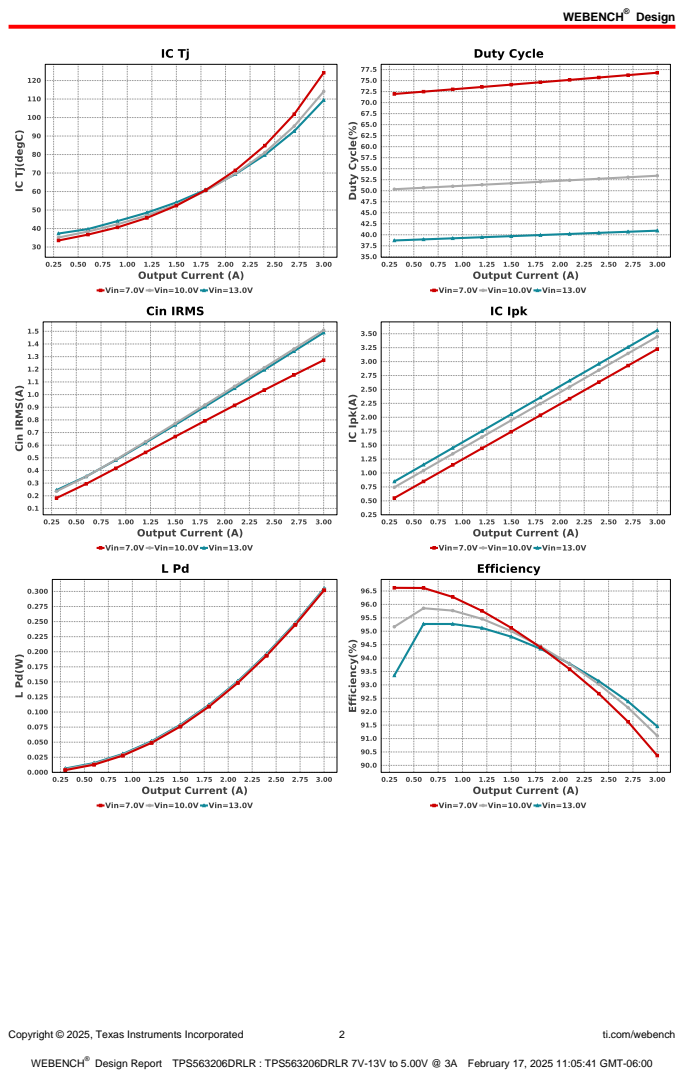
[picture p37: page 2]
Design; Copyright © 2025, Texas Instruments Incorporated; ti.com/webench

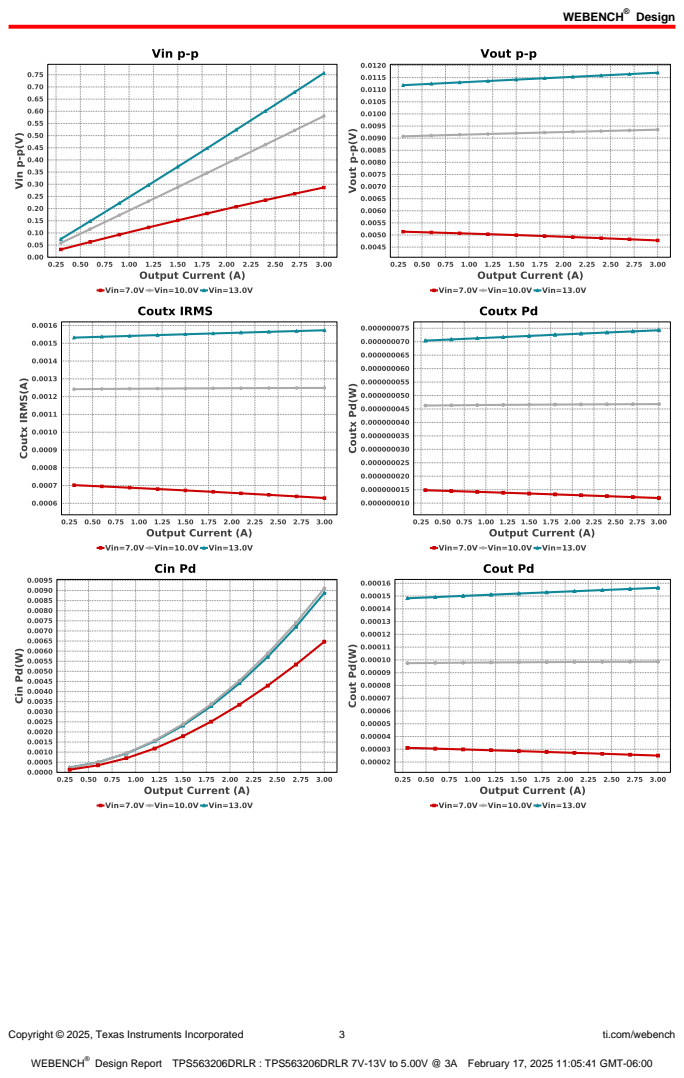
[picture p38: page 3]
Copyright © 2025, Texas Instruments Incorporated; ti.com/webench

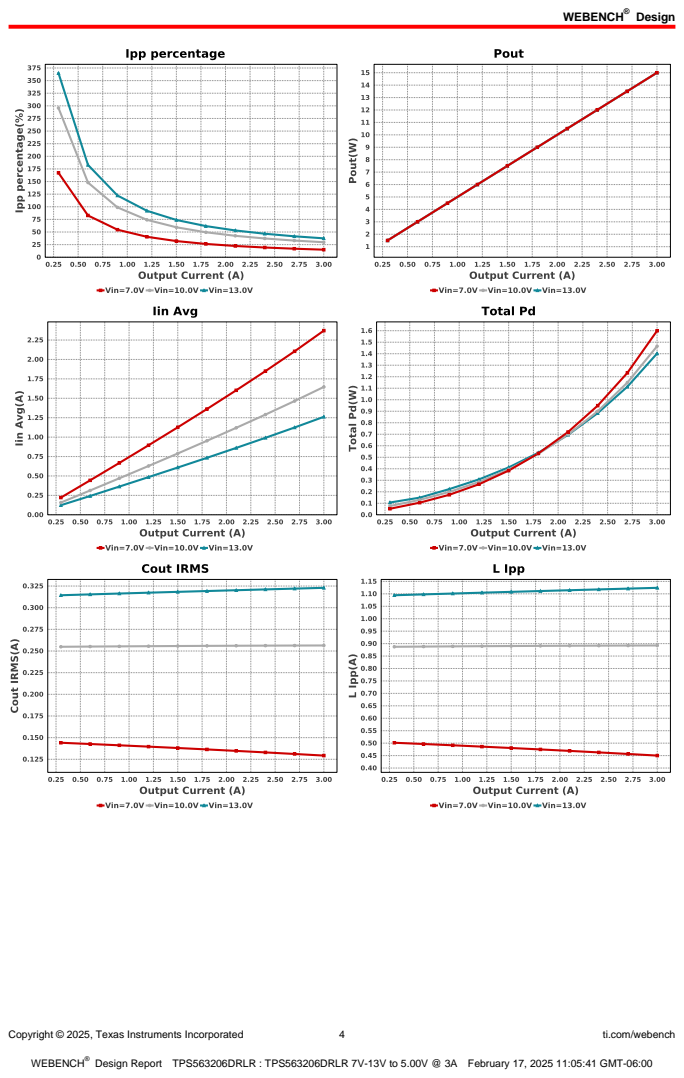
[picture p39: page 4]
Copyright © 2025, Texas Instruments Incorporated; ti.com/webench

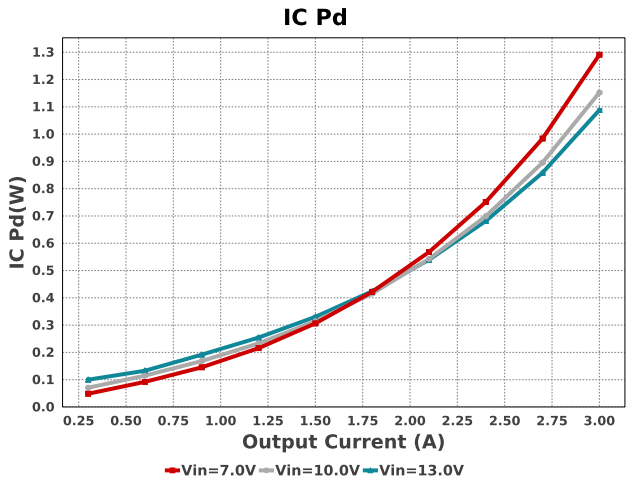
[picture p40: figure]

Copyright © 2025, Texas Instruments Incorporated | 5 | ti.com/webench

## Operating Values

# | Name | Value | Category | Description

1. Cin IRMS | 1.49 A | Capacitor | Input capacitor RMS ripple current
2. Cin Pd | 8.876 mW | Capacitor | Input capacitor power dissipation
3. Cout IRMS | 322.938 mA | Capacitor | Output capacitor RMS ripple current
4. Cout Pd | 156.43 µW | Capacitor | Output capacitor power dissipation
5. Coutx IRMS | 1.573 mA | Capacitor | Output capacitor_x RMS ripple current
6. Coutx Pd | 74.256 nW | Capacitor | Output capacitor_x power loss
7. IC Ipk | 3.562 A | IC | Peak switch current in IC
8. IC Pd | 1.088 W | IC | IC power dissipation
9. IC Tj | 109.421 degC | IC | IC junction temperature
10. IC Tolerance | 9.0 mV | IC | IC Feedback Tolerance
11. ICThetaJA Effective | 73.0 degC/W | IC | IC junction-to-ambient thermal resistance with TI EVM
12. Iin Avg | 1.262 A | IC | Average input current
13. Ipp percentage | 37.471 % | Inductor | Inductor ripple current percentage (with respect to average inductor
| | | | current)
14. L Ipp | 1.124 A | Inductor | Peak-to-peak inductor ripple current
15. L Pd | 304.83 mW | Inductor | Inductor power dissipation
16. Cin Pd | 8.876 mW | Power | Input capacitor power dissipation
17. Cout Pd | 156.43 µW | Power | Output capacitor power dissipation
18. Coutx Pd | 74.256 nW | Power | Output capacitor_x power loss
19. IC Pd | 1.088 W | Power | IC power dissipation
20. L Pd | 304.83 mW | Power | Inductor power dissipation
21. Total Pd | 1.402 W | Power | Total Power Dissipation
22. BOM Count | 12 | System
| | | Information | Total Design BOM count
23. Duty Cycle | 40.93 % | System
| | | Information | Duty cycle
24. Efficiency | 91.453 % | System
| | | Information | Steady state efficiency
25. FootPrint | 129.0 mm² | System
| | | Information | Total Foot Print Area of BOM components
26. Frequency | 588.035 kHz | System
| | | Information | Switching frequency
27. Iout | 3.0 A | System
| | | Information | Iout operating point
28. Mode | CCM | System
| | | Information | Conduction Mode
29. Pout | 15.0 W | System
| | | Information | Total output power
30. Total BOM | $2.01 | System
| | | Information | Total BOM Cost
31. Vin | 13.0 V | System
| | | Information | Vin operating point
32. Vin p-p | 756.731 mV | System
| | | Information | Peak-to-peak input voltage
33. Vout | 5.0 V | System
| | | Information | Operational Output Voltage
34. Vout Actual | 5.0 V | System
| | | Information | Vout Actual calculated based on selected voltage divider resistors
35. Vout Tolerance | 3.304 % | System
| | | Information | Vout Tolerance based on IC Tolerance (no load) and voltage divider resistors if applicable
36. Vout p-p | 11.702 mV | System
| | | Information | Peak-to-peak output ripple voltage

Copyright © 2025, Texas Instruments Incorporated | 6 | ti.com/webench

## Design Inputs

Name | Value | Description
Iout | 3.0 | Maximum Output Current
VinMax | 13.0 | Maximum input voltage
VinMin | 7.0 | Minimum input voltage
Vout | 5.0 | Output Voltage
base_pn | TPS563206 | Base Product Number
source | DC | Input Source Type
Ta | 30.0 | Ambient temperature


Copyright © 2025, Texas Instruments Incorporated | 7 | ti.com/webench

## Assembly
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

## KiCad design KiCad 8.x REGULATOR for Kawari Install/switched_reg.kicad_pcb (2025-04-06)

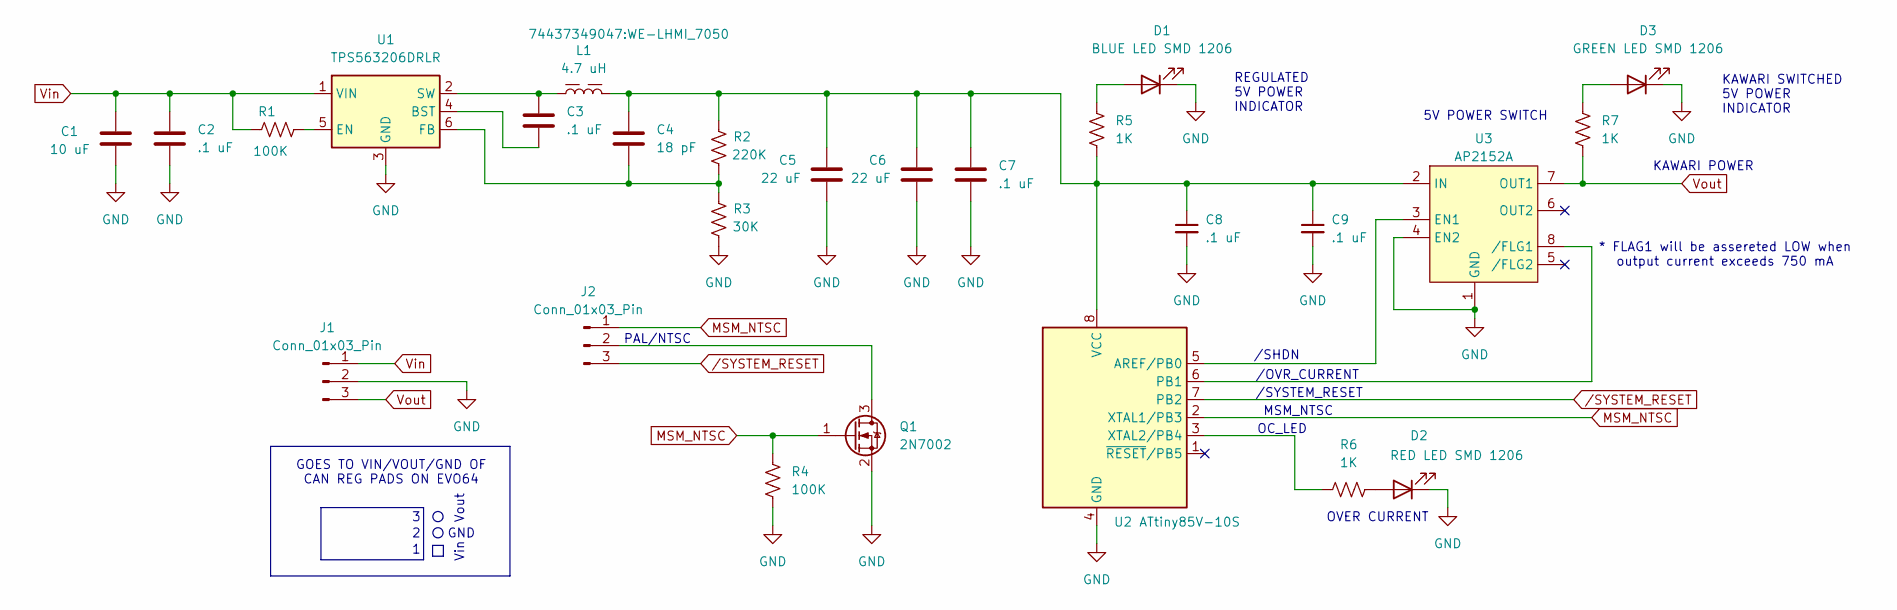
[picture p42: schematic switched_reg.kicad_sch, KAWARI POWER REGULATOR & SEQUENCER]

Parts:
C1: 10 uF; C_0805_2012Metric
C2, C3, C7, C8, C9: .1 uF; C_0805_2012Metric
C4: 18 pF; C_0805_2012Metric
C5, C6: 22 uF; C_0805_2012Metric
D1: BLUE LED SMD 1206; LED_1206_3216Metric
D2: RED LED SMD 1206; LED_1206_3216Metric
D3: GREEN LED SMD 1206; LED_1206_3216Metric
J1, J2: Conn_01x03_Pin; PinHeader_1x03_P2.54mm_Vertical
L1: 4.7 uH; WE-LHMI_7050
Q1: 2N7002; SOT-23
R1, R4: 100K; R_0805_2012Metric
R2: 220K; R_0805_2012Metric
R3: 30K; R_0805_2012Metric
R5, R6, R7: 1K; R_0805_2012Metric
U1: TPS563206DRLR; SOT-563
U2: ATtiny85V-10S; SOIC-8W_5.3x5.3mm_P1.27mm
U3: AP2152A; SO-8_3.9x4.9mm_P1.27mm

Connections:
GND: C1.2, C2.2, C5.2, C6.2, C7.2, C8.2, C9.2, D1.1 (K), D2.1 (K), D3.1 (K), J1.2, Q1.2 (S), R3.2, R4.2, U1.3 (GND), U2.4 (GND), U3.1 (GND), U3.4 (EN2)
MSM_NTSC: J2.1, Q1.1 (G), R4.1, U2.2 (XTAL1/PB3)
unnamed: D1.2 (A), R5.1
unnamed: D2.2 (A), R6.2
unnamed: D3.2 (A), R7.1
unnamed: J2.2, Q1.3 (D)
unnamed: C3.2, U1.4 (BST)
unnamed: R1.2, U1.5 (EN)
unnamed: C4.2, R2.2, R3.1, U1.6 (FB)
unnamed: C3.1, L1.1, U1.2 (SW)
unnamed: U2.5 (AREF/PB0), U3.3 (EN1)
unnamed: U2.6 (PB1), U3.8 (/FLG1)
unnamed: C4.1, C5.1, C6.1, C7.1, C8.1, C9.1, L1.2, R2.1, R5.2, U2.8 (VCC), U3.2 (IN)
unnamed: R6.1, U2.3 (XTAL2/PB4)
Vin: C1.1, C2.1, J1.1, R1.1, U1.1 (VIN)
Vout: J1.3, R7.2, U3.7 (OUT1)
/SYSTEM_RESET: J2.3, U2.7 (PB2)

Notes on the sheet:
* FLAG1 will be assereted LOW when output current exceeds 750 mA
MSM_NTSC
/OVR_CURRENT
GOES TO VIN/VOUT/GND OF CAN REG PADS ON EVO64
Vin
/SHDN
5V POWER SWITCH
Vout
KAWARI POWER
KAWARI SWITCHED 5V POWER INDICATOR
GND
OVER CURRENT
OC_LED
/SYSTEM_RESET
REGULATED 5V POWER INDICATOR
PAL/NTSC

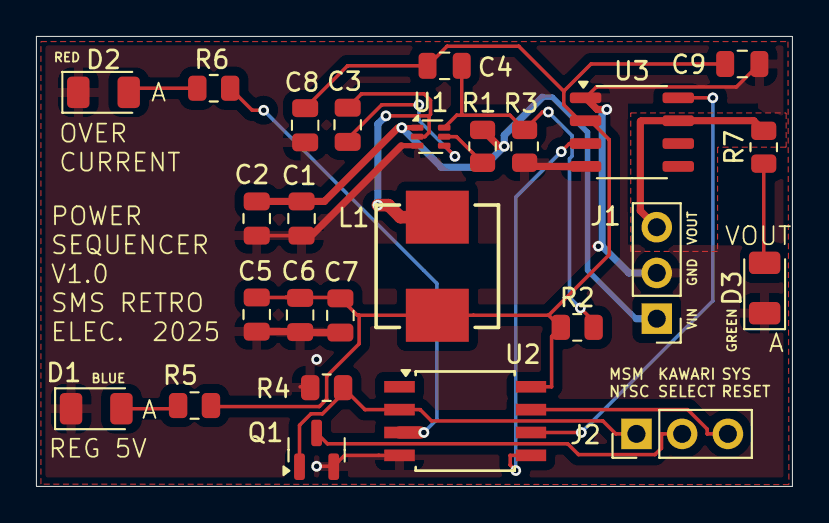
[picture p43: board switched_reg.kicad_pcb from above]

Board: 2 copper layers, 42.0 x 25.0 mm, 26 parts (0 on the bottom side), 17 nets.

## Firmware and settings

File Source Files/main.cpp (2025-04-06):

/*  ; MIT License
;
; Copyright (c) 2025 William Manganaro sMs Retro Electronics
;
; Permission is hereby granted, free of charge, to any person obtaining a copy of this software
; and associated documentation files (the "Software"), to deal in the Software without
; restriction, including without limitation the rights to use, copy, modify, merge, publish,
; distribute, sublicense, and/or sell copies of the Software, and to permit persons to whom
; the Software is furnished to do so, subject to the following conditions:
;
; The above copyright notice and this permission notice shall be included in all copies or
; substantial portions of the Software.
;
; THE SOFTWARE IS PROVIDED "AS IS", WITHOUT WARRANTY OF ANY KIND, EXPRESS OR IMPLIED, INCLUDING
; BUT NOT LIMITED TO THE WARRANTIES OF MERCHANTABILITY, FITNESS FOR A PARTICULAR PURPOSE AND
; NONINFRINGEMENT. IN NO EVENT SHALL THE AUTHORS OR COPYRIGHT HOLDERS BE LIABLE FOR ANY CLAIM,
; DAMAGES OR OTHER LIABILITY, WHETHER IN AN ACTION OF CONTRACT, TORT OR OTHERWISE, ARISING FROM,
; OUT OF OR IN CONNECTION WITH THE SOFTWARE OR THE USE OR OTHER DEALINGS IN THE SOFTWARE.
*/

// Firmware operation
//
// The purpose of this software is to allow fro the Kawari VICII hardware emulator to switch 
// between NTSC and PAL video modes when commanded by an Retrospective EVO64 MSM controller without
// the need to recycle the computer power. It also provides an OVER CURRENT feature that will switch
// the power OFF to the Kawari if the current is >= 750 milliamperes. 
//Operation
//
// This firmware monitors any
// change from the NTSC (or the PAL) logic output from the MSM and electronically cycles the power
// to the Kawari Vcc pin. This cycle is as follows: Turn power OFF when a change is detected 
// , keep the power off until the boards RESET is asserted, at this point the power is returned to ON.
// Overcurrent is latching. If an over current condition is detected, the firmware will turn the power 
// OFF to the Kawari Vcc pin and remain OFF until the next system power cycle.
// all status is indicated with different color LED's 

#include <Arduino.h>

// pin defines
#define shdn 0
#define oc 1
#define sreset 2
#define edge_det 3
#define oc_led 4

// isr here:

ISR(PCINT0_vect) // this is the Interrupt Service Routine
{
  delay(20);                       // wait 20 milliseconds after switch over
  digitalWrite(shdn, LOW);         // turn the power OFF to the Kawari
  while (digitalRead(sreset) == 1) // wait for reset to get issued
  {
  }
  digitalWrite(shdn, HIGH); // turn power ON to Kawari
}

void setup()
{

  pinMode(shdn, OUTPUT);
  delay(100);
  digitalWrite(shdn, HIGH); // turn power ON to Kawari
  pinMode(oc_led, OUTPUT);
  digitalWrite(oc_led, LOW);
  pinMode(oc, INPUT_PULLUP);
  pinMode(sreset, INPUT_PULLUP);
  pinMode(edge_det, INPUT_PULLUP);
  PCMSK |= bit(PCINT3);  // eNABLE PIN CHANGE INTERRUPT ON pin D3 (PIN 2 OF mcu)
  GIFR = 0;              // clear any outstanding interrupt flags
  GIMSK |= bit(PCIE);    // globally enable pin change interrupts
  SREG |= (1 << SREG_I); // globally enable interrupts
}

void loop()
{
  digitalWrite(shdn, HIGH);    // turn power ON to Kawari
  while (digitalRead(oc) == 1) // just sit here while no over current condition exists
  {
  }
  SREG = (0 << SREG_I);       // globally disable interrupts
  digitalWrite(shdn, LOW);    // turn the power OFF to the Kawari
  digitalWrite(oc_led, HIGH); // turn overcurrect indicator on
  while (1)
    ; // do nothing until next power cycle, overcurrent condition will remain latched
}

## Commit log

2025-04-09 Added more build Instructions & Files
    Added more build Instructions & Files
    [switched_reg-B_Cu.gbl, switched_reg-B_Mask.gbs, switched_reg-B_Paste.gbp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]
2025-04-14 BOM Changes
    Added and corrected part numbers. Added part descriptions
    [bom.csv]

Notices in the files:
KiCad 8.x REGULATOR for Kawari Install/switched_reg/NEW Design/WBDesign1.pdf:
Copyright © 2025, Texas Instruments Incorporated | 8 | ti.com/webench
